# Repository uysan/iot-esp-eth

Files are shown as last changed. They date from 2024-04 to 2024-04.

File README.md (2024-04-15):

# ESP32 Ethernet, Wi-Fi & Serial Gateway

_Open Source Hardware Developed With Open Source Software_ [*](#development-software)

## Overview

<picture>
  <source media="(prefers-color-scheme: dark)" srcset="./pcb/3dviewb.png">
  <source media="(prefers-color-scheme: light)" srcset="./pcb/3dvieww.png">
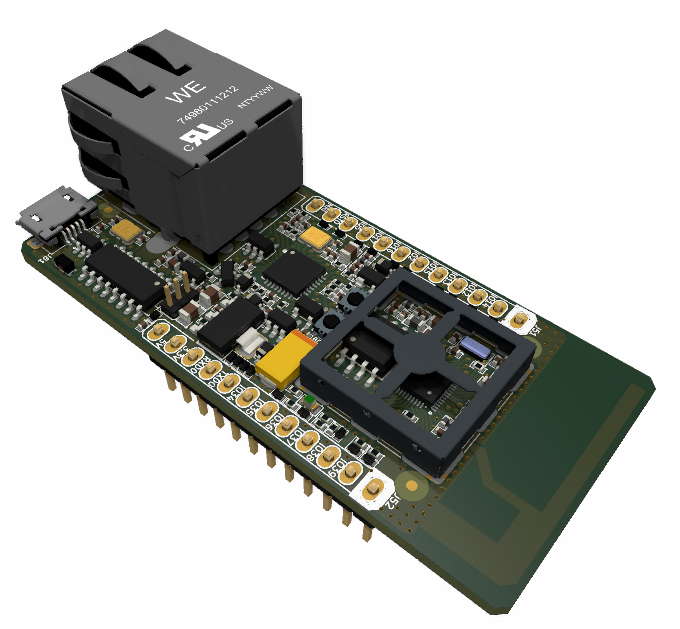
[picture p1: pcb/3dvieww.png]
3D view.
  
</picture>

A hardware design which includes ESP32, Ethernet, Wi-Fi, USB and serial connectivity. **iot-esp-eth** is suitable to use as a gateway between Ethernet, Wi-Fi and serial. When used with [esp-at](https://github.com/espressif/esp-at) project, you can connect wired or wireless networks with AT commands sent to USB or serial ports. You may also operate it with custom firmware, since it is not different from a usual ESP32 development kit.

**iot-esp-eth** may be used as an attachment to a base board. Standalone usage with USB supply is possible as well.

ESP-IDF automatic bootloader activation is supported on USB port. This port is connected to UART0 of ESP32.

Schematic, PCB layout and antenna design are available in this repository. **iot-esp-eth** is compatible with many example projects at [espressif](https://github.com/espressif/) github repository.

## Table of Contents

- [PCB Design](./pcb/) : KiCAD project including schematic, layout, BOM, Gerber files.
- [Antenna Design](./antenna/) : OpenEMS project for PCB antenna design including simulation scripts, figures and prototype measurements.
- [Firmware](./firmware/) : espressif/esp-at project modified to include iot-esp-eth configuration.
- [Documents](./document/) : Project files for diagrams and documents.

## Pinout Diagram

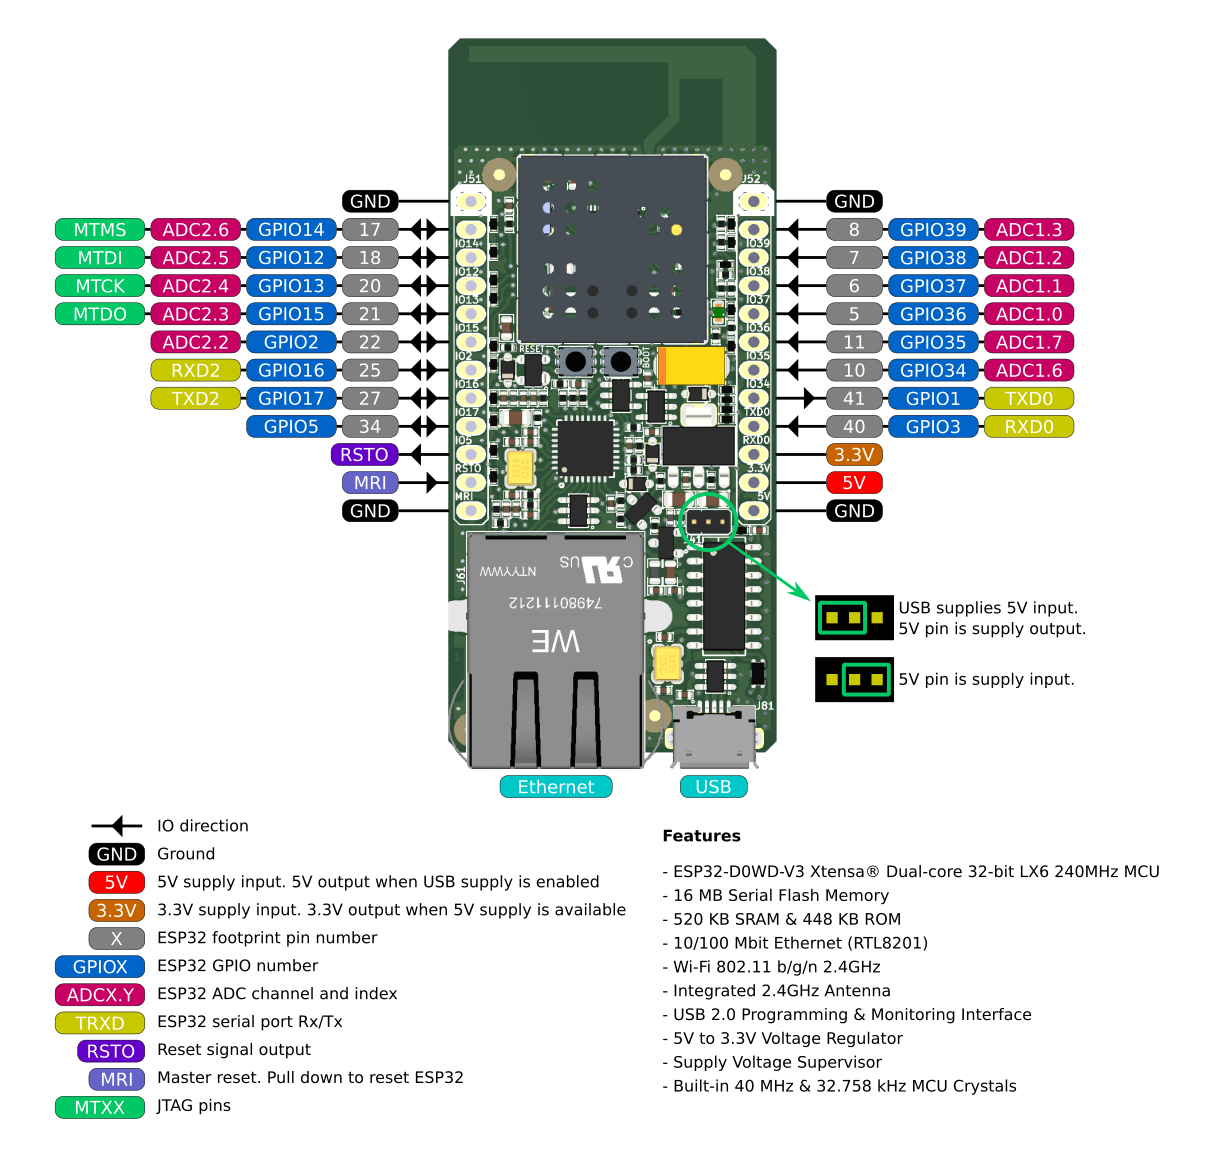
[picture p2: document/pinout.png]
Pinout


## Block Diagram

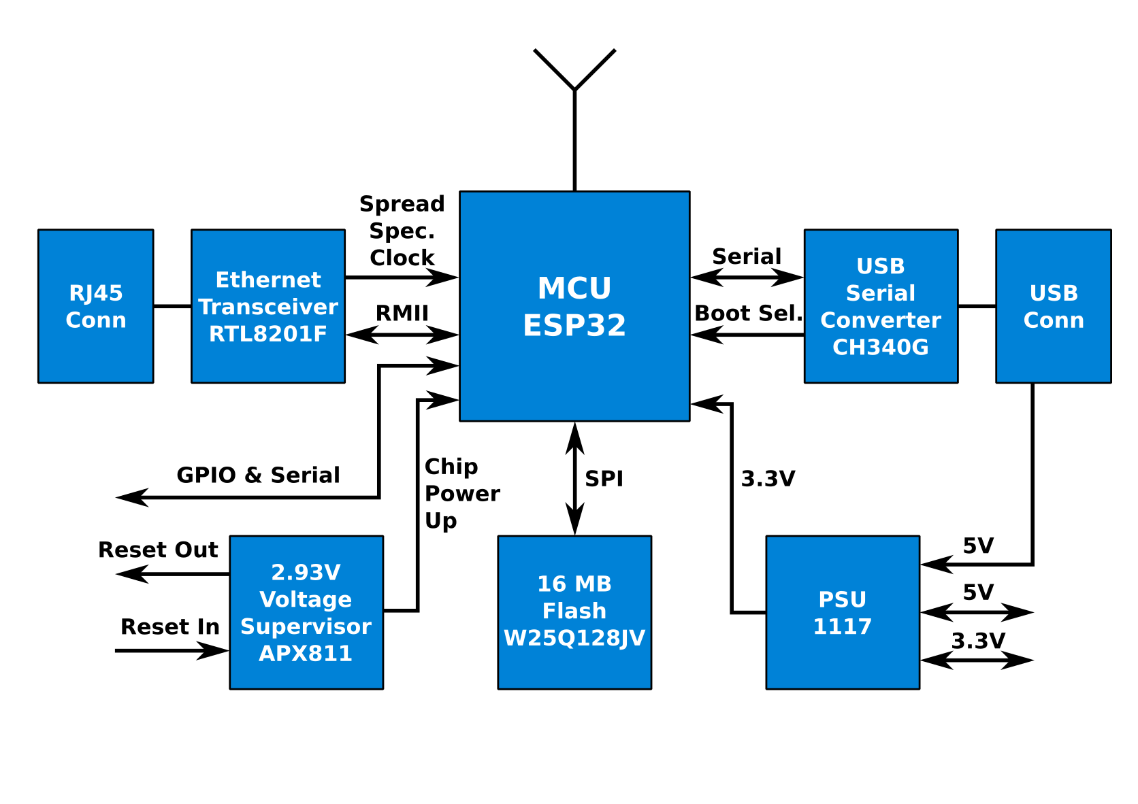
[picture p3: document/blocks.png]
Blocks


## Datasheet

[UYS2101IA, UYS2101CA - ESP32 Ethernet, Wi-Fi & Serial Gateway](./document/uys2101.pdf)

## Features

- ESP32-D0WD-V3 Xtensa® Dual-core 32-bit LX6 240MHz MCU 
- 16 MB Serial Flash Memory
- 520 KB SRAM & 448 KB ROM
- 10/100 Mbit Ethernet (RTL8201F)
- Wi-Fi 802.11 b/g/n 2.4GHz
- Integrated 2.4GHz Antenna
- USB 2.0 Programming & Monitoring Interface
- 5V to 3.3V Voltage Regulator
- Supply Voltage Supervisor
- Built-in 40 MHz & 32.758 kHz MCU Crystals

## Development Software

This project was developed with open source tools including but not limited to KiCAD, OpenEMS, Octave, FreeCAD, Paraview, Inkscape and Scribus on a PC running Ubuntu Desktop edition.

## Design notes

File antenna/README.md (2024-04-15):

# ESP32 Ethernet, Wi-Fi & Serial Gateway

_Open Source Hardware Developed With Open Source Software_ [*](#development-software)

## Antenna Design, Simulation and Measurement

<picture>
  <source media="(prefers-color-scheme: dark)" srcset="../pcb/antviewb.png">
  <source media="(prefers-color-scheme: light)" srcset="../pcb/antvieww.png">
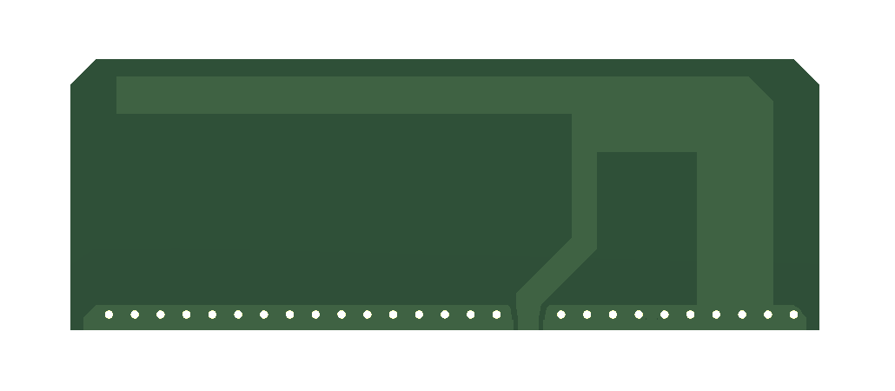
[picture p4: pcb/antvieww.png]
3D view.
  
</picture>

Antenna simulations are made with OpenEMS. The board layout and critical components are defined as geometries in an Octave script.

Initially, coarse dimensions for Inverted-F antenna are obtained from text books and entered to script. Then many iterations are made with OpenEMS to match antenna impedance to 50 ohms at the center frequency (2440MHz). At the same time, VSWR should be acceptable for the operation range from 2400 to 2480 MHz.

The board layout is defined exactly the same as the 4-layer stack up definitions from the manufacturer. If another stack up or material to be used, simulations and prototypes should be updated accordingly.

When the simulation results are satisfactory, geometries are exported from AppCSXCAD and imported to KiCAD to draw the board edges and the antenna as exactly as possible.

Antenna measurements are made with a LiteVNA64. The calibration is done with high-frequency SMD resistors on the matching components' pads since using SMA or similar connectors alters the results drastically.

S1P file exported from VNA is imported to smith chart software (SimNEC) to calculate the matching component values to match ESP32 output impedance to 50 ohms antenna impedance.

It can be seen that the measurement results are consistent with the simulations.

View of geometries before simulation:

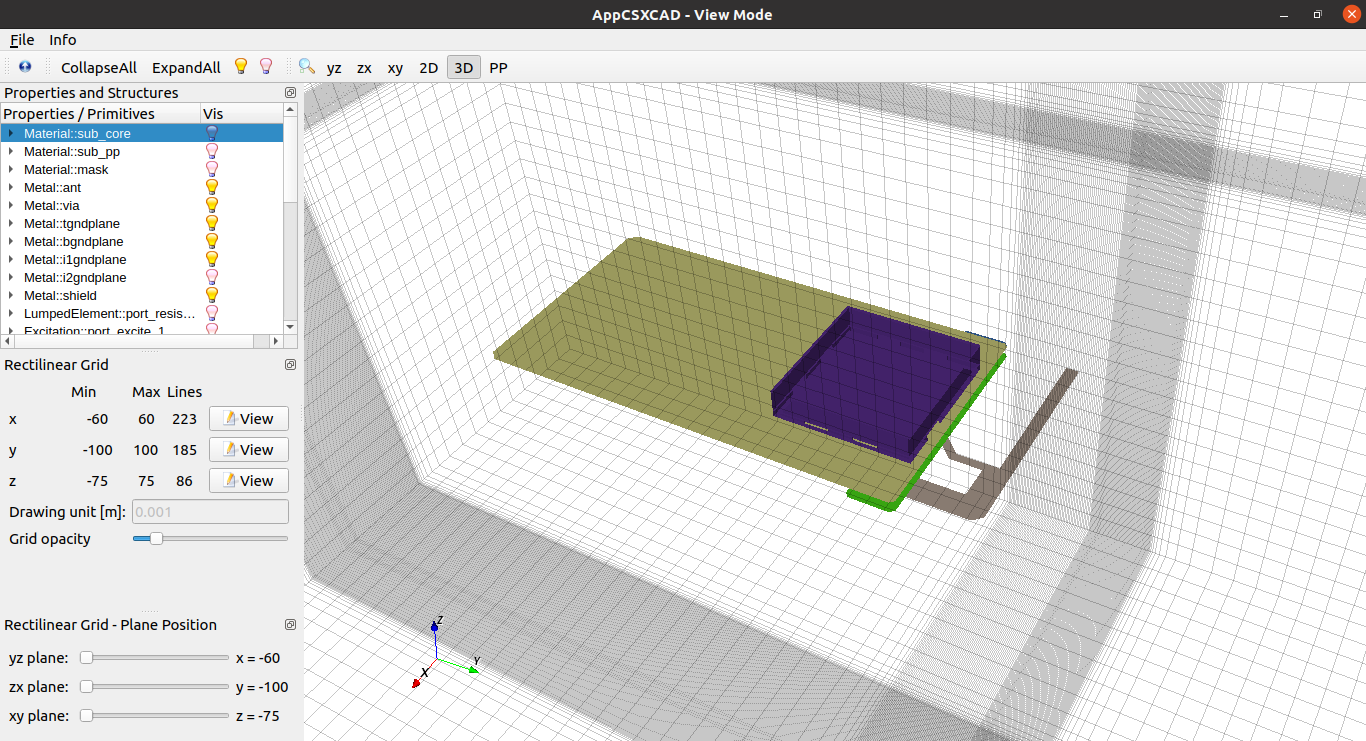
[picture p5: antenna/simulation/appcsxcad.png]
AppCSXCAD


Simulated S11 parameters:

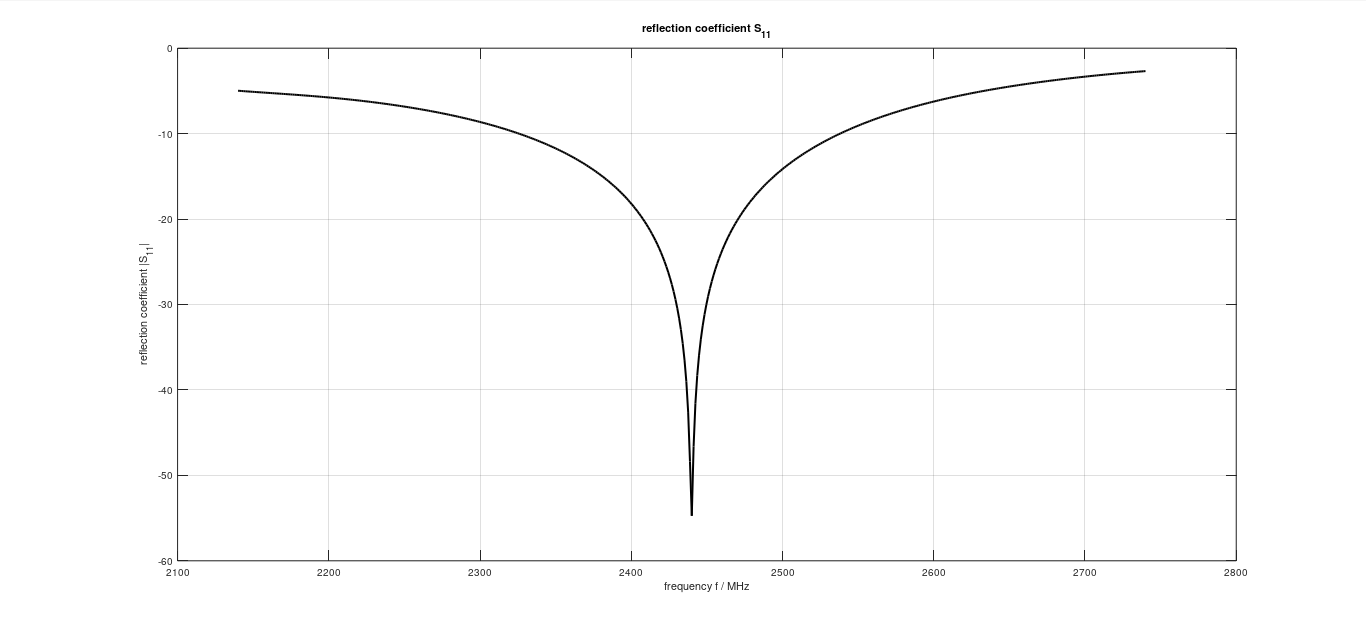
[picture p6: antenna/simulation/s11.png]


Simulated smith chart:

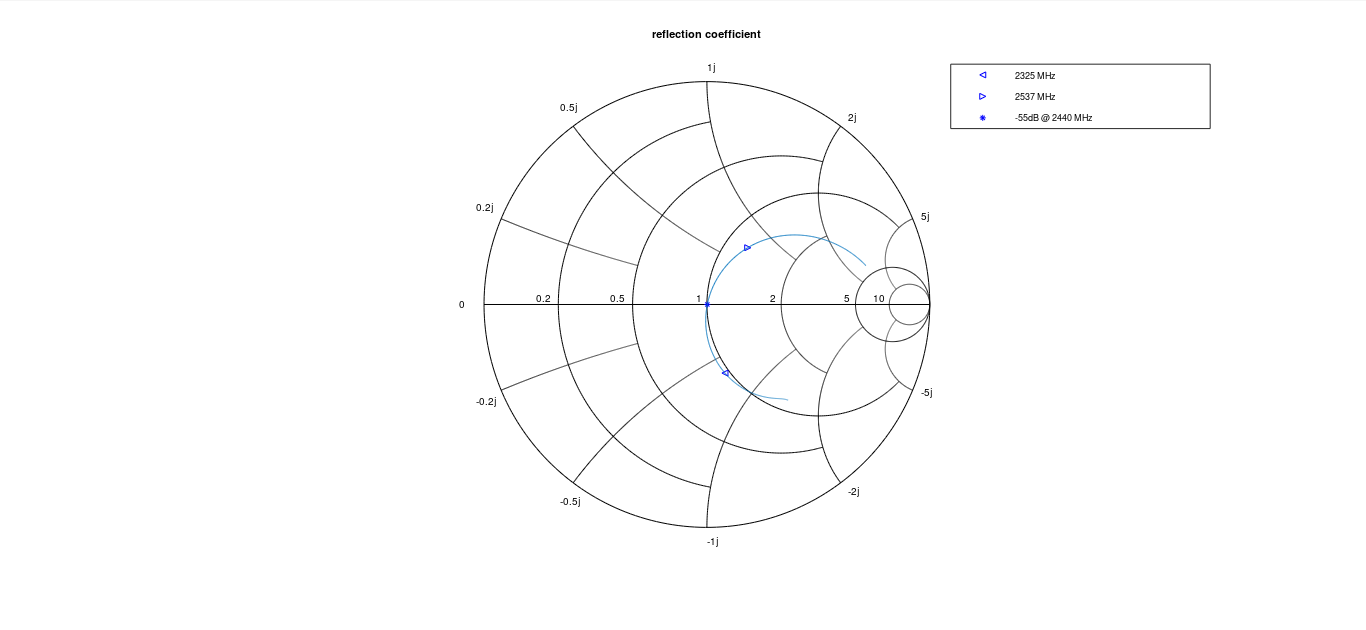
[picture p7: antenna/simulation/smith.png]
smith


Simulated feed point impedance:

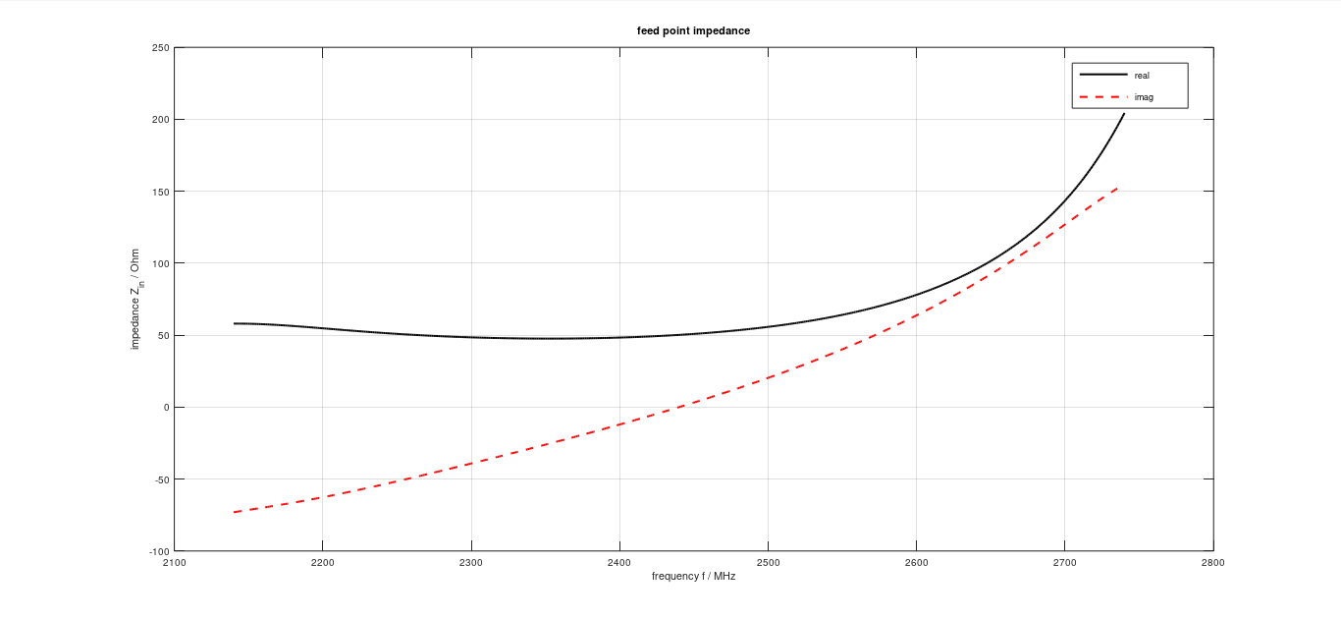
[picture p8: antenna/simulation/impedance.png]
impedance


Simulated 3D radiation:

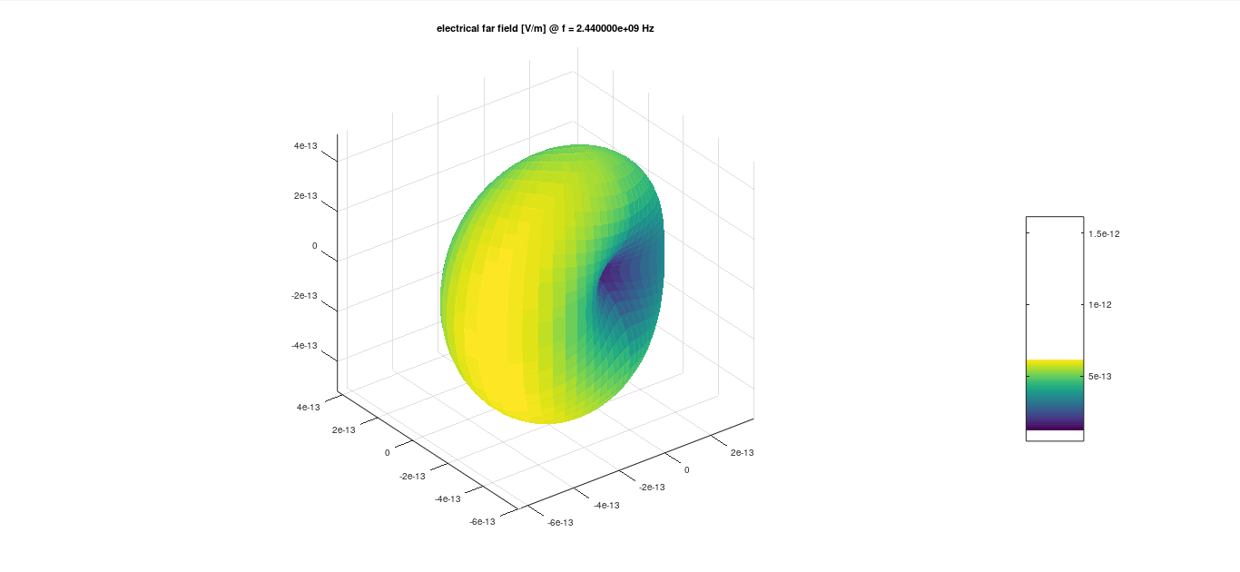
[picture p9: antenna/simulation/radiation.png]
radiation


Measured S11 parameters:

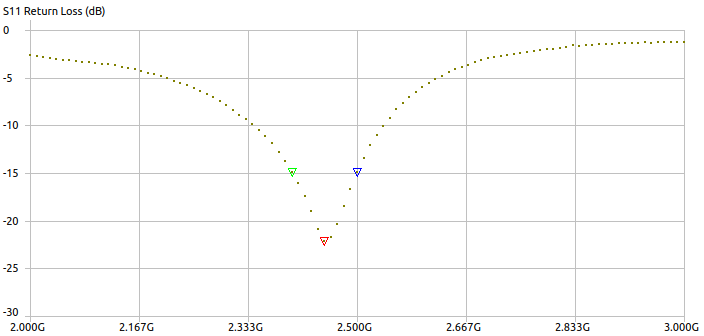
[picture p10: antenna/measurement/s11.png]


Measured smith chart:

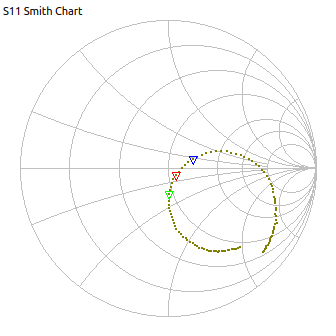
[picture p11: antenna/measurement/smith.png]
smith


Measured phase graph:

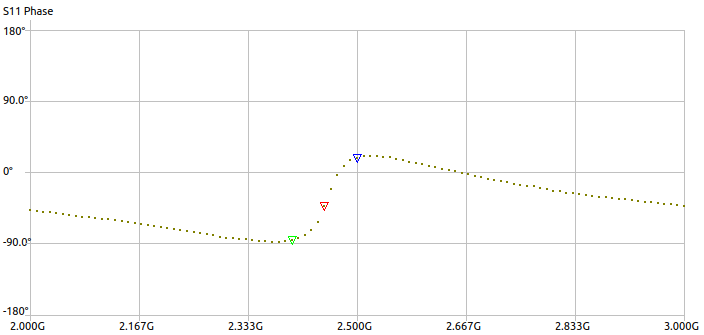
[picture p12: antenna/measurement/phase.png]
phase


## Files

[Octave Simulation Script](./simulation.m)

[Simulation Results And Figures](./simulation/)

[VNA Measurements](./measurement/)

[VNA Measurement Data](./measurement/measurement.s1p)

[Exported Geometries](./stl/)

## Development Software

This project was developed with open source tools including but not limited to KiCAD, OpenEMS, Octave, FreeCAD, Paraview, Inkscape and Scribus on a PC running Ubuntu Desktop edition.

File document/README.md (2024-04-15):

# ESP32 Ethernet, Wi-Fi & Serial Gateway

_Open Source Hardware Developed With Open Source Software_ [*](#development-software)

## Overview

This directory contains Inkscape SVG files, drawings and documents.

## Development Software

This project was developed with open source tools including but not limited to KiCAD, OpenEMS, Octave, FreeCAD, Paraview, Inkscape and Scribus on a PC running Ubuntu Desktop edition.

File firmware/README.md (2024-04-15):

# ESP32 Ethernet, Wi-Fi & Serial Gateway

_Open Source Hardware Developed With Open Source Software_ [*](#development-software)

## Overview

Default firmware on **iot-esp-eth** board is a modified version of [esp-at](https://github.com/espressif/esp-at) project. This project is linked to this repository as a submodule. After initializing the submodule, you can apply the necessary patch and compile the code for **iot-esp-eth**.

Clone the project into your local directory:
```
git clone https://github.com/uysan/iot-esp-eth.git
```

Initialize esp-at submodule and apply the patch:
```
cd iot-esp-eth/
git submodule update --init --depth 1
git apply firmware/esp-at.patch
```

Install esp-idf environment and tools:
```
cd firmware/esp-at/
./build.py install
```

Build script asks for some configuration:
```
Platform name:
1. PLATFORM_ESP32
2. PLATFORM_ESP32C3
3. PLATFORM_ESP32C2
4. PLATFORM_ESP32C6
choose(range[1,4]): 1  <-- Enter 1 here

Module name:
1. WROOM-32
2. WROVER-32
3. PICO-D4
4. SOLO-1
5. MINI-1 (description: ESP32-U4WDH chip inside)
6. ESP32-SDIO
7. ESP32-D2WD (description: 2MB flash, No OTA)
8. IOT-ESP-ETH (description: 16MB flash, Ethernet)
choose(range[1,8]): 8  <-- Enter 8 here

Enable silence mode to remove some logs and reduce the firmware size?
0. No
1. Yes
choose(range[0,1]): 1  <-- Enter 1 here
```

Build the code:
```
./build.py build
```

Then connect iot-esp-eth board to your computer with a USB cable and upload the firmware:
```
./build.py -p /dev/ttyUSB0 flash
```

You may use your preferred serial terminal software to enter AT commands. For picocom:
```
picocom /dev/ttyUSB0 -b 115200 --omap crcrlf
```

## Development Software

This project was developed with open source tools including but not limited to KiCAD, OpenEMS, Octave, FreeCAD, Paraview, Inkscape and Scribus on a PC running Ubuntu Desktop edition.

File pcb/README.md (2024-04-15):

# ESP32 Ethernet, Wi-Fi & Serial Gateway

_Open Source Hardware Developed With Open Source Software_ [*](#development-software)

## Overview

> [!NOTE]
> This directory contains two versions of **iot-esp-eth** hardware design. There are small differences between board layouts, but bill of materials differ a lot. Components of the **iot-esp-eth-ind** board has an operating range of -40॰C to +85॰C, whereas the **iot-esp-eth-com** board is for 0॰C to 70॰C.
> Both have 4-layers and are designed according to the JLCPCB impedance controlled stack up of [JLC04161H-7628](https://jlcpcb.com/impedance).

**iot-esp-eth** design is based on Espressif ESP32-D0WD-V3 Xtensa® Dual-core 32-bit LX6 240MHz MCU. It has 520 kB SRAM and 448 kB ROM but no flash memory. Winbond W25Q128JVSIQ SPI flash chip is used as an application and data storage with a 16MB capacity. One 40MHz and one 32.768kHz crystal are used as clock sources of the MCU. These components are enclosed with an RF shield to decrease EMC interference.

Wi-Fi and 2.4GHz wireless are built in ESP32. The only required external component is an antenna. An Inverted-F type PCB antenna is designed for **iot-esp-eth** by using EM simulation tools. Since the output impedance of ESP32's RF amplifier is different from 50 ohms, an L-type matching circuit is populated.

ESP32 has an RMII interface. Realtek RTL8201F transceiver is connected through this interface for Ethernet connectivity. Ethernet transformers are included in the RJ45 connector and this leads to a compact design. Ethernet clock is generated by RTL8201F and supplied to the ESP32. This chip has spread spectrum ability to lower radiated emissions. There is a 3-state buffer (74AUP1G126) on the clock signal to disable the clock while ESP32 is initializing. The clock input of ESP32 (GPIO0) is a bootstrapped input.

**iot-esp-eth** has two extension pin headers in order to connect it to another custom design base boards.

ESP32's UART0 is used for flash programming and general purpose cases. This port is connected to both extension pin header and the Serial-USB converter chip (CH340G). There is an AND gate (74AHC1G08) between RXD pins to prevent shorts when USB and serial port pins are used at the same time. ESP-IDF's automatic bootloader activation is supported on USB port.

**iot-esp-eth** has an onboard 5 to 3.3V linear regulator. It is possible to supply the board with 5V or 3.3V via the extension headers. If USB power is available, 5V and 3.3V pins on the headers can supply exernal circuits.

There is a voltage supervisory chip to generate reset pulses 200ms wide when necessary or when the voltage drops below minimum required. Two buttons can be used to reset the circuit or enter serial bootloader after reset.

**iot-esp-eth** has ESD protection on extension headers, antenna, Ethernet and USB ports, and has common mode chokes on Ethernet and USB ports.

## Images

Copper layers:

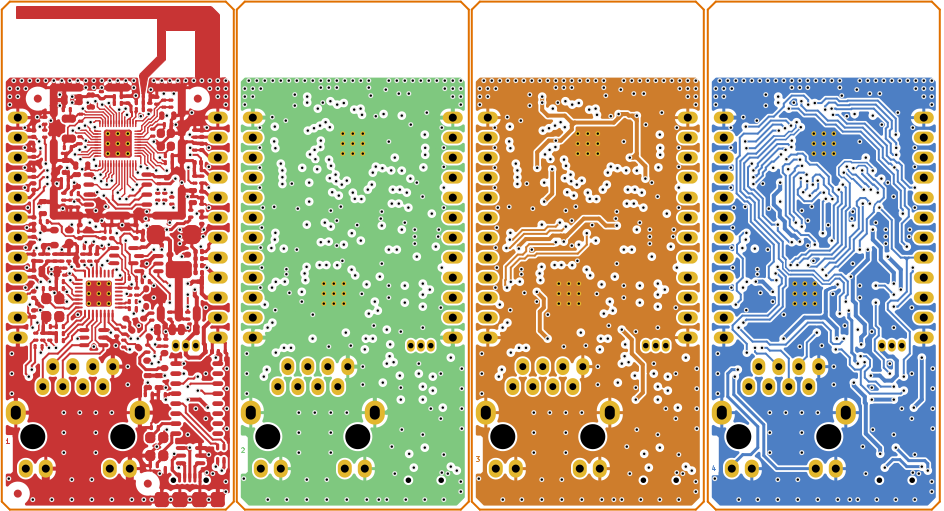
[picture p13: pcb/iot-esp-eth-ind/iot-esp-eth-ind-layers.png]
Copper layers.


Top view:

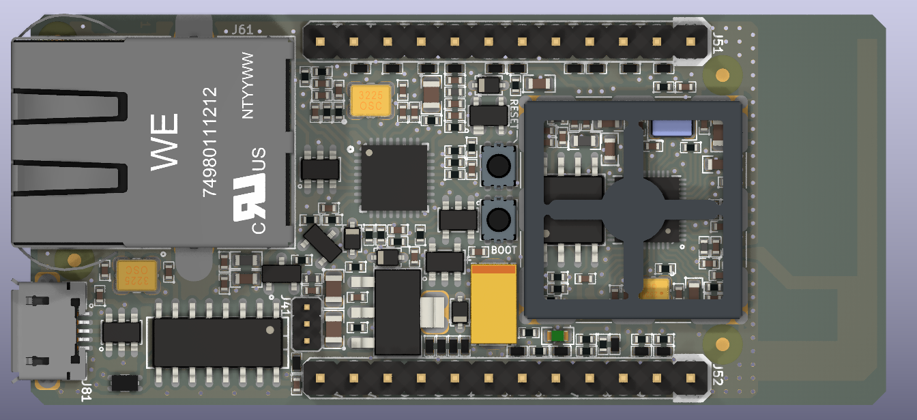
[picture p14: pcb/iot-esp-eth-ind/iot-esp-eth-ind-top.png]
Top view.


Bottom view:

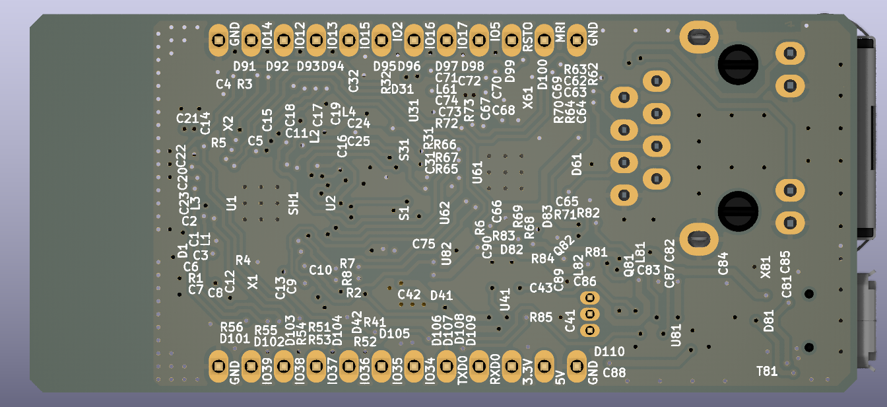
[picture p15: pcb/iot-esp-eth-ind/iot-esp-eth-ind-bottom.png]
Bottom view.


## Development Software

This project was developed with open source tools including but not limited to KiCAD, OpenEMS, Octave, FreeCAD, Paraview, Inkscape and Scribus on a PC running Ubuntu Desktop edition.

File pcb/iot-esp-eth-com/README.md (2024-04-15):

# ESP32 Ethernet, Wi-Fi & Serial Gateway

_Open Source Hardware Developed With Open Source Software_ [*](#development-software)

## Overview

This directory contains KiCAD project files, generated PCB images, Gerber, panel configuration files, interactive HTML based assembly list, bill of materials and position (pick & place) data.

Components of the **iot-esp-eth-com** board has an operating range of 0॰C to 70॰C. Board layout has 4-layers and is designed according to the JLCPCB impedance controlled stack up of [JLC04161H-7628](https://jlcpcb.com/impedance).

PCB panels can be automatically generated with KiKit (KiCAD plugin). Configuration files are in the related directory.

## Files

[Schematics](./iot-esp-eth-com.pdf)

[PCB Layers](./iot-esp-eth-com-layers.pdf)

[Bill of Materials](./iot-esp-eth-com-bom.csv)

[Position Data](./iot-esp-eth-com-all-pos.csv)

[Interactive assembly part list](./bom/ibom.html)

[Panel Configuration](./panel/config.json)

[Dimensions](./iot-esp-eth-com-dimensions.pdf)

## Images

Copper layers:

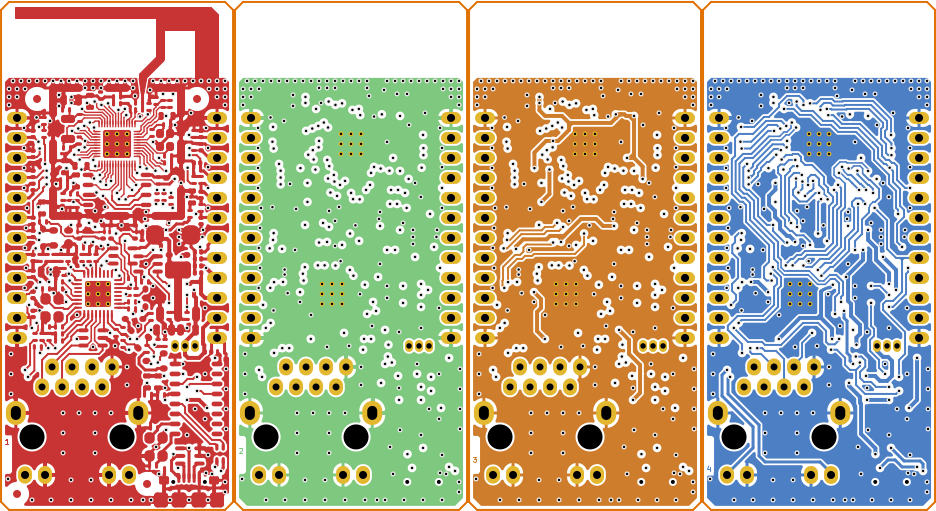
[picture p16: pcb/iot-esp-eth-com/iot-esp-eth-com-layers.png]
Copper layers.


Top view:

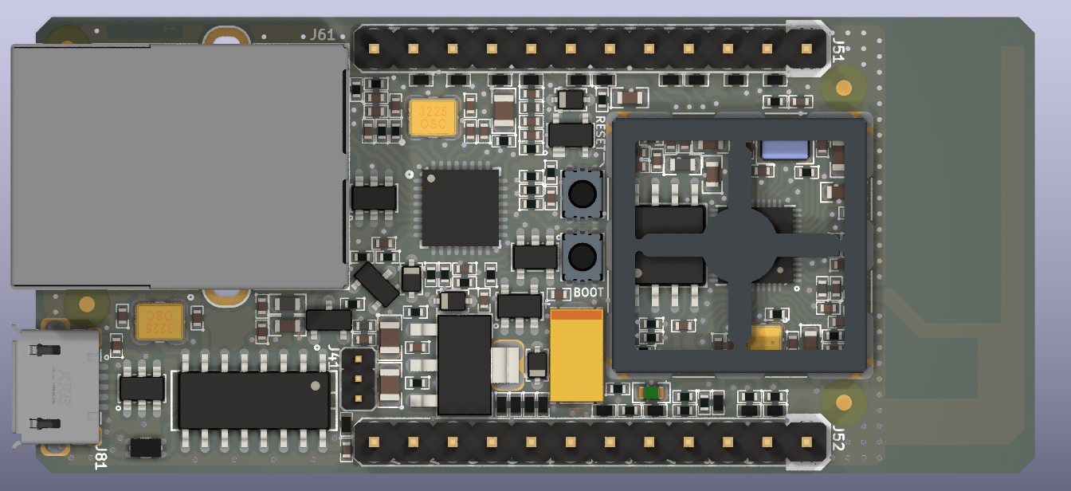
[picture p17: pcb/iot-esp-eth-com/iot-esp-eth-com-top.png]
Top view.


Bottom view:

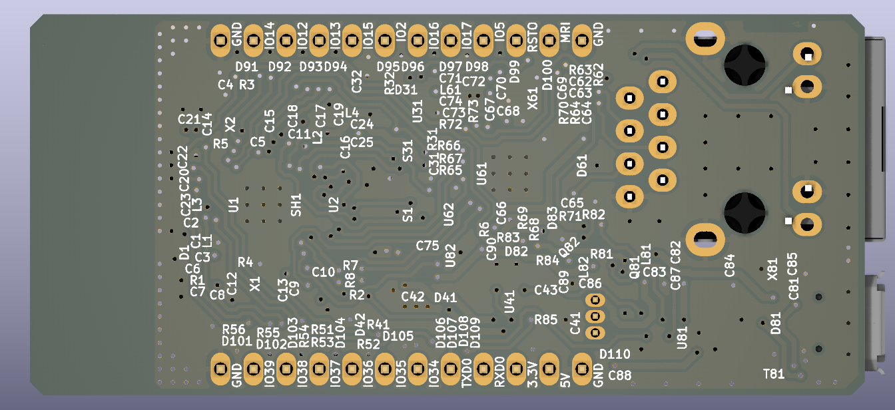
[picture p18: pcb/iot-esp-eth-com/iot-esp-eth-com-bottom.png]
Bottom view.


## Development Software

This project was developed with open source tools including but not limited to KiCAD, OpenEMS, Octave, FreeCAD, Paraview, Inkscape and Scribus on a PC running Ubuntu Desktop edition.

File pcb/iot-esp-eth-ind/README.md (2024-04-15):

# ESP32 Ethernet, Wi-Fi & Serial Gateway

_Open Source Hardware Developed With Open Source Software_ [*](#development-software)

## Overview

This directory contains KiCAD project files, generated PCB images, Gerber, panel configuration files, interactive HTML based assembly list, bill of materials and position (pick & place) data.

Components of the **iot-esp-eth-ind** board has an operating range of -40॰C to +85॰C. Board layout has 4-layers and is designed according to the JLCPCB impedance controlled stack up of [JLC04161H-7628](https://jlcpcb.com/impedance).

PCB panels can be automatically generated with KiKit (KiCAD plugin). Configuration files are in the related directory.

## Files

[Schematics](./iot-esp-eth-ind.pdf)

[PCB Layers](./iot-esp-eth-ind-layers.pdf)

[Bill of Materials](./iot-esp-eth-ind-bom.csv)

[Position Data](./iot-esp-eth-ind-all-pos.csv)

[Interactive assembly part list](./bom/ibom.html)

[Panel Configuration](./panel/config.json)

[Dimensions](./iot-esp-eth-ind-dimensions.pdf)

## Images

Copper layers:

Copper layers.

Top view:

Top view.

Bottom view:

Bottom view.

## Development Software

This project was developed with open source tools including but not limited to KiCAD, OpenEMS, Octave, FreeCAD, Paraview, Inkscape and Scribus on a PC running Ubuntu Desktop edition.

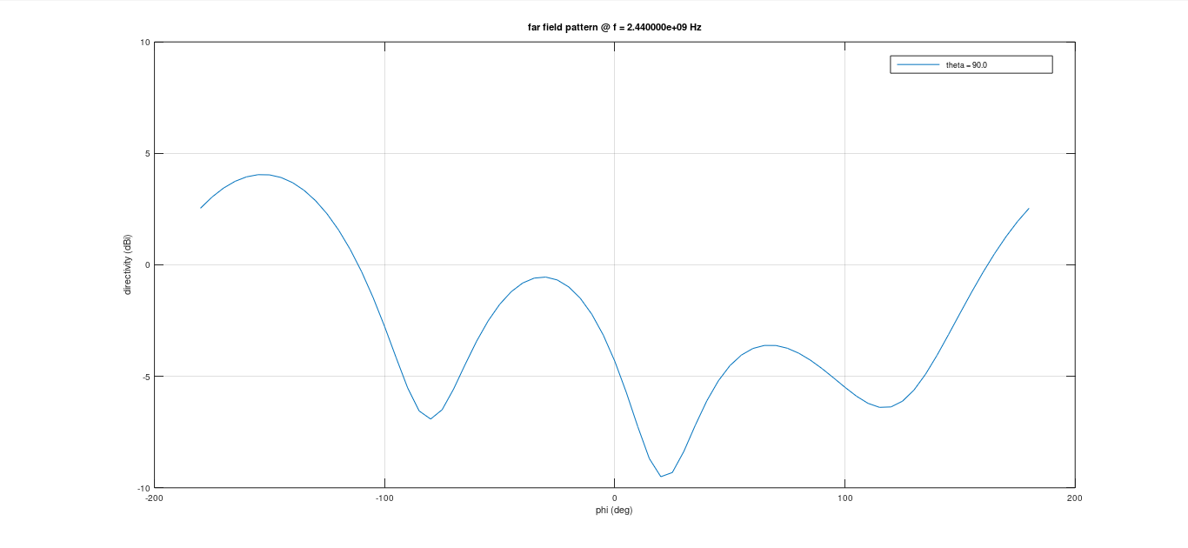
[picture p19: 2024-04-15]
antenna/simulation/ff2.png

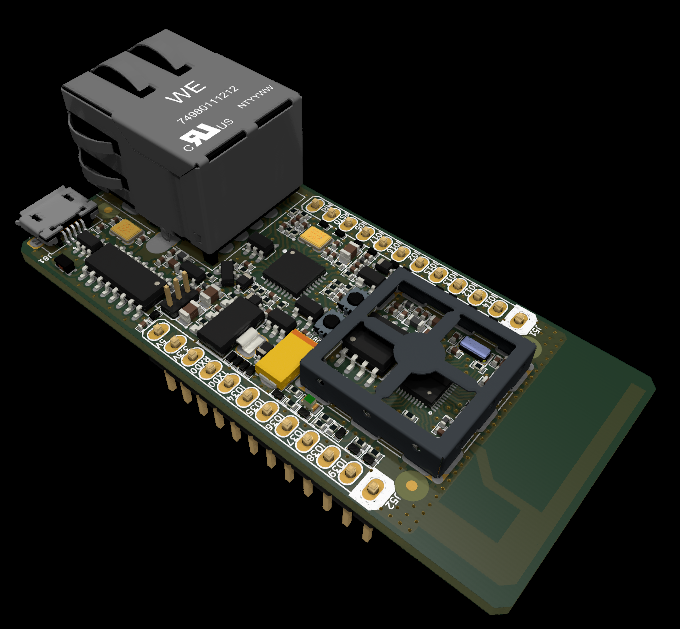
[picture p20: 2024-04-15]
pcb/3dviewb.png

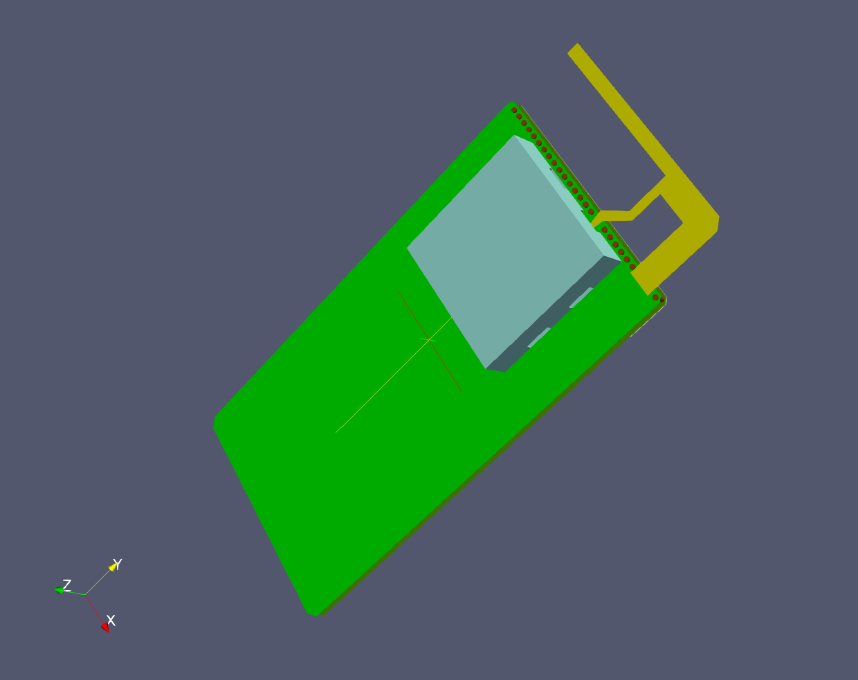
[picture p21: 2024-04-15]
antenna/simulation/paraview.png

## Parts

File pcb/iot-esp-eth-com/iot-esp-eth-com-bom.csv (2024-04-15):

Reference | Quantity | Value | Footprint | Datasheet | Digikey | Manufacturer | PartNumber | Power | Temperature | Tolerance
C1 | 1 | 0.9pF/50V | Celebi:SM0402C | https://www.we-online.com/catalog/datasheet/885392005022.pdf | !13-CC0402BRNPO9BNR90CT-ND | Wurth | 885392005022 | _ | -55+125°C | 0.1pF
C12,C13 | 2 | 12pF/50V | Celebi:SM0402C | https://www.yageo.com/en/Chart/Download/pdf/CC0402JRNPO9BN120 | 311-1016-1-ND | Yageo | CC0402JRNPO9BN120 | _ | -55+125°C | 5%
C14,C15,C69,C70 | 4 | 18pF/50V | Celebi:SM0402C | https://www.yageo.com/en/Chart/Download/pdf/CC0402JRNPO9BN180 | 311-1415-1-ND | Yageo | CC0402JRNPO9BN180 | _ | -55+125°C | 5%
C10,C16,C17,C2,C20,C25,C3,C31,C43,C5,C62,C63,C64,C65,C66,C67,C68,C71,C74,C75,C86,C87,C88,C90 | 24 | 100nF/16V | Celebi:SM0402C | http://weblib.samsungsem.com/mlcc/mlcc-ec-data-sheet.do?partNumber=CL05B104KO5NNN | 1276-1001-1-ND | Samsung | CL05B104KO5NNNC | _ | -55+125°C | 10%
C21,C41,C72,C89 | 4 | 10uF/16V | Celebi:SM0805C | http://weblib.samsungsem.com/mlcc/mlcc-ec-data-sheet.do?partNumber=CL21B106KOQNNN | 1276-2872-1-ND | Samsung | CL21B106KOQNNNE | _ | -55+125°C | 10%
C32 | 1 | 100nF/50V | Celebi:SM0603C | http://weblib.samsungsem.com/mlcc/mlcc-ec-data-sheet.do?partNumber=CL10B104KB8NNN | 1276-1000-1-ND | Samsung | CL10B104KB8NNNC | _ | -55+125°C | 10%
C4,C7 | 2 | 3.3nF/50V | Celebi:SM0402C | http://weblib.samsungsem.com/mlcc/mlcc-ec-data-sheet.do?partNumber=CL05B332KB5NNN | 1276-1552-1-ND | Samsung | CL05B332KB5NNNC | _ | -55+125°C | 10%
C42 | 1 | 47uF/16V | Celebi:SMD-C-6032 | https://spicat.kyocera-avx.com/product/tan/chartview/TAJC476K016RNJ/DataSheet/gen_taj/TAJC476_016_NJ | 478-1718-1-ND | Kyocera_AVX | TAJC476K016RNJ | _ | -55+125°C | 10%
C6 | 1 | 10nF/50V | Celebi:SM0402C | https://www.yageo.com/en/Chart/Download/pdf/CC0402KRX7R9BB103 | 311-1349-1-ND | Yageo | CC0402KRX7R9BB103 | _ | -55+125°C | 10%
C11,C18,C22,C8,C83 | 5 | 1uF/16V | Celebi:SM0603C | https://www.yageo.com/en/Chart/Download/pdf/CC0603KRX7R7BB105 | 311-1446-1-ND | Yageo | CC0603KRX7R7BB105 | _ | -55+125°C | 10%
C81 | 1 | 100nF/50V | Celebi:SM0402C | https://www.yageo.com/en/Chart/Download/pdf/CC0402KRX7R9BB104 | 311-3566-1-ND | Yageo | CC0402KRX7R9BB104 | _ | -55+125°C | 10%
C84,C85 | 2 | 27pF/50V | Celebi:SM0402C | https://www.yageo.com/en/Chart/Download/pdf/CC0402JRNPO9BN270 | 311-1019-1-ND | Yageo | CC0402JRNPO9BN270 | _ | -55+125°C | 5%
C19,C23,C24,C73,C82,C9 | 6 | 15pF/50V | Celebi:SM0402C | https://www.yageo.com/en/Chart/Download/pdf/CC0402JRNPO9BN150 | 311-1017-1-ND | Yageo | CC0402JRNPO9BN150 | _ | -55+125°C | 5%
D1 | 1 | TVS_4V | Celebi:SM0402V | https://www.murata.com/products/productdata/8796832759838/CRESD-E.pdf | 490-13210-2-ND | Murata | LXES15AAA1-153 | 15kV | -40+85°C | _
D31,D41,D82,D83 | 4 | BAT54WS | Celebi:SOD323 | https://www.panjit.com.tw/upload/datasheet/BAT54WS.pdf | 3757-BAT54WS_R1_00001CT-ND | Panjit | BAT54WS_R1_00001 | 0.2A | -55+125°C | _
D42 | 1 | Diode-LED_Green | Celebi:led-SM0603_Green | https://optoelectronics.liteon.com/upload/download/DS22-2000-228/LTST-C191KGKT.PDF | 160-1446-1-ND | Liteon | LTST-C191KGKT | 0.075W | -55+85°C | _
D61,D81 | 2 | TVS_5V | Celebi:SOT23-6L | https://en.leiditech.com/u_file/file/products/2212/13/392447b971.pdf | !497-4492-1-ND | Leiditech | USRV05-4 | 350W | -55+125°C | _
D100,D101,D102,D103,D104,D105,D106,D107,D108,D109,D110,D91,D92,D93,D94,D95,D96,D97,D98,D99 | 20 | TVS_5V | Celebi:DFN1006-2 | https://en.leiditech.com/u_file/file/products/2212/16/1ac2f97961.pdf | !490-12804-1-ND | Leiditech | ULC0511CDN | 110W | -55+150°C | _
E41 | 1 | Jumper | Celebi:N.A. | https://datasheet.lcsc.com/lcsc/2201121830_XKB-Connectivity-X1301-B1NIB_C2938575.pdf | !S9345-ND | XKB | X1301-B1NIB | 1A | -40+105°C | _
J41 | 1 | Conn_01x03 | Celebi:sil-1.27mm-3P | https://www.helloxkb.com/public/images/pdf/X1311WV-XXJ-C18D27.pdf | !SAM10238-ND | XKB | X1311WV-03J-C18D27 | 1A | -40+105°C | _
J51,J52 | 2 | Conn_01x12/DNP | Celebi:sil-12P | https://www.helloxkb.com/public/images/pdf/X6511WV-XXH-C60D30.pdf | !S1012EC-12-ND | XKB | X6511WV-12H-C60D30 | 3A | -40+105°C | _
J61 | 1 | HR913550A | Celebi:eth-HR911105A | https://datasheet.lcsc.com/lcsc/1811141123_HANRUN-Zhongshan-HanRun-Elec-HR913550A_C163507.pdf | _ | Hanrun | HR913550A | _ | 0+85°C | _
J81 | 1 | USB-Micro | Celebi:usb-U253-05XX-4BH89-XXS | http://www.helloxkb.com/public/images/pdf/U253-05XX-4BH89-XXS.pdf | !732-3155-1-ND | XKB | U253-051N-4BH89-S1S | 1A | -40+85°C | _
L1 | 1 | 2.2nH | Celebi:SM0402L | https://www.we-online.com/catalog/datasheet/7447840022G.pdf | 732-7447840022GCT-ND | Wurth | 7447840022G | 0.3A | -55+125°C | 0.1nH
L2,L81 | 2 | Bead_300R | Celebi:SM0603L | https://www.we-online.com/catalog/datasheet/742792641.pdf | 732-1592-1-ND | Wurth | 742792641 | 2A | -55+125°C | 25%
L3 | 1 | 2nH | Celebi:SM0402L | https://www.we-online.com/catalog/datasheet/744765020A.pdf | 732-1705-1-ND | Wurth | 744765020A | 1.04A | -40+125°C | 0.2nH
L4 | 1 | Bead_220R/DNP | Celebi:SM0402L | https://www.we-online.com/catalog/datasheet/742792780.pdf | 732-1569-1-ND | Wurth | 742792780 | 0.3A | -55+125°C | 25%
L61,L82 | 2 | Bead_220R | Celebi:SM0402L | https://www.we-online.com/catalog/datasheet/742792780.pdf | 732-1569-1-ND | Wurth | 742792780 | 0.3A | -55+125°C | 25%
M1 | 1 | Shield_Cover | Celebi:N.A. | https://www.we-online.com/catalog/datasheet/36003160s.pdf | 732-11644-1-ND | Wurth | 36003160S | _ | -40+125°C | _
Q81,Q82 | 2 | BC817 | Celebi:SOT23-3 | https://assets.nexperia.com/documents/data-sheet/BC817_SER.pdf | 1727-2919-1-ND | Nexperia | BC817-40-215 | 0.5A | -65+150°C | _
R1 | 1 | 20k | Celebi:SM0402 | https://www.yageo.com/upload/media/product/productsearch/datasheet/rchip/PYu-RC_Group_51_RoHS_L_12.pdf | 311-20.0KLRCT-ND | Yageo | RC0402FR-0720KL | 1/16W | -55+155°C | 1%
R2 | 1 | 499R | Celebi:SM0402 | https://www.yageo.com/upload/media/product/productsearch/datasheet/rchip/PYu-RC_Group_51_RoHS_L_12.pdf | 311-499LRCT-ND | Yageo | RC0402FR-07499RL | 1/16W | -55+155°C | 1%
R3,R32 | 2 | 100R | Celebi:SM0402 | https://www.yageo.com/upload/media/product/productsearch/datasheet/rchip/PYu-RC_Group_51_RoHS_L_12.pdf | 311-100LRCT-ND | Yageo | RC0402FR-07100RL | 1/16W | -55+155°C | 1%
R31 | 1 | 100k | Celebi:SM0402 | https://www.yageo.com/upload/media/product/productsearch/datasheet/rchip/PYu-RC_Group_51_RoHS_L_12.pdf | 311-100KLRCT-ND | Yageo | RC0402FR-07100KL | 1/16W | -55+155°C | 1%
R4 | 1 | 0R | Celebi:SM0402 | https://www.yageo.com/upload/media/product/productsearch/datasheet/rchip/PYu-RC_Group_51_RoHS_L_12.pdf | 311-0.0JRCT-ND | Yageo | RC0402JR-070RL | 1/16W | -55+155°C | Jumper
R41 | 1 | 2k7 | Celebi:SM0402 | https://www.yageo.com/upload/media/product/productsearch/datasheet/rchip/PYu-RC_Group_51_RoHS_L_12.pdf | 311-2.70KLRCT-ND | Yageo | RC0402FR-072K7L | 1/16W | -55+155°C | 1%
R5 | 1 | 10Meg | Celebi:SM0402 | https://www.yageo.com/upload/media/product/productsearch/datasheet/rchip/PYu-RC_Group_51_RoHS_L_12.pdf | 311-10.0MLRCT-ND | Yageo | RC0402FR-0710ML | 1/16W | -55+155°C | 1%
R51,R52,R53,R54,R55,R56 | 6 | 470k | Celebi:SM0402 | https://www.yageo.com/upload/media/product/productsearch/datasheet/rchip/Pyu-RC_Group_51_RoHS_L_12.pdf | 311-470KLRCT-ND | Yageo | RC0402FR-07470KL | 1/16W | -55+155°C | 1%
R6,R62,R63,R83,R84 | 5 | 1k | Celebi:SM0402 | https://www.yageo.com/upload/media/product/productsearch/datasheet/rchip/PYu-RC_Group_51_RoHS_L_12.pdf | 311-1.00KLRCT-ND | Yageo | RC0402FR-071KL | 1/16W | -55+155°C | 1%
R64 | 1 | 2k49 | Celebi:SM0402 | https://www.yageo.com/upload/media/product/productsearch/datasheet/rchip/PYu-RC_Group_51_RoHS_L_12.pdf | 311-2.49KLRCT-ND | Yageo | RC0402FR-072K49L | 1/16W | -55+155°C | 1%
R65,R85 | 2 | 47k | Celebi:SM0402 | https://www.yageo.com/upload/media/product/productsearch/datasheet/rchip/PYu-RC_Group_51_RoHS_L_12.pdf | 311-47.0KLRCT-ND | Yageo | RC0402FR-0747KL | 1/16W | -55+155°C | 1%
R66,R67,R81,R82 | 4 | 10k | Celebi:SM0402 | https://www.yageo.com/upload/media/product/productsearch/datasheet/rchip/PYu-RC_Group_51_RoHS_L_12.pdf | 311-10.0KLRCT-ND | Yageo | RC0402FR-0710KL | 1/16W | -55+155°C | 1%
R68,R69,R7,R70,R8 | 5 | 22R | Celebi:SM0402 | https://www.yageo.com/upload/media/product/productsearch/datasheet/rchip/PYu-RC_Group_51_RoHS_L_12.pdf | 311-22.0LRCT-ND | Yageo | RC0402FR-0722RL | 1/16W | -55+155°C | 1%
R71,R72,R73 | 3 | 4k7 | Celebi:SM0402 | https://www.yageo.com/upload/media/product/productsearch/datasheet/rchip/PYu-RC_Group_51_RoHS_L_12.pdf | 311-4.7KLRCT-ND | Yageo | RC0402FR-074K7L | 1/16W | -55+155°C | 1%
S1,S31 | 2 | Tact_Switch | Celebi:switch-WE-WS-TASV-3x2.6_H1.4mm | https://www.dg-switch.com/uploads/soft/190720/GT-TX171X-H014-LX.pdf | !732-435171014816CT-ND | G-Switch | GT-TC171A-H014-L1 | 0.05A | -30+85°C | _
SH1 | 1 | Shield | Celebi:shield-36103166S | https://www.we-online.com/catalog/datasheet/36103166s.pdf | 732-11652-1-ND | Wurth | 36103166S | _ | -40+125°C | _
T81 | 1 | CM_Choke_90R | Celebi:tr-smd-WE-CNSW_0805 | https://www.sunlordinc.com/uploads/files/20230829/SDCW%20series%20of%20Wire%20Wound%20Chip%20Common%20Mode%20Choke%20Coil.pdf | !732-3198-1-ND | Sunlord | SDCW2012-2-900TF | 0.33A | -40+85°C | _
U1 | 1 | ESP32-D0WD | Celebi:QFN48_5x5_P0.35_E3.5mm | https://www.espressif.com/sites/default/files/documentation/esp32_datasheet_en.pdf | 1904-ESP32-D0WD-V3CT-ND | Espressif | ESP32-D0WD-V3 | _ | -40+125°C | _
U2 | 1 | W25Q128JV | Celebi:SO8_5.2x5.2_P1.27mm | https://www.winbond.com/resource-files/W25Q128JV%20RevI%2008232021%20Plus.pdf | W25Q128JVSIQ-ND | Winbond | W25Q128JVSIQ | _ | -40+85°C | _
U31 | 1 | APX811_2.93V | Celebi:SOT143-4 | https://www.diodes.com/assets/Datasheets/APX811_812.pdf | APX811-29UG-7DICT-ND | Diodes | APX811-29UG-7 | _ | -40+85°C | 2%
U41 | 1 | AMS1117-3.3 | Celebi:SOT223 | https://mm.digikey.com/Volume0/opasdata/d220001/medias/docus/5011/AMS1117.pdf | 4518-AMS1117-3.3CT-ND | UMW | AMS1117-3.3 | 1A | -40+125°C | 1.5%
U61 | 1 | RTL8201F | Celebi:QFN32_5x5_P0.5_E3.35mm | https://www.semiee.com/file/Source10/REALTEK-RTL8201F-VB-CG.pdf | _ | Realtek | RTL8201F-VB-CG | _ | 0+70°C | _
U62 | 1 | 74AUP1G126 | Celebi:SOT23-5L | https://www.ti.com/lit/ds/symlink/sn74aup1g126.pdf | 296-18005-1-ND | Texas_Instruments | SN74AUP1G126DBVR | 0.05A | -40+125°C | _
U81 | 1 | CH340G | Celebi:SO16_4x10.5_P1.27mm | http://www.wch-ic.com/downloads/file/79.html | _ | WCH | CH340G | _ | -40+85°C | _
U82 | 1 | 74AHC1G08 | Celebi:SOT23-5L | https://www.ti.com/lit/ds/symlink/sn74ahc1g08.pdf | 296-1091-1-ND | Texas_Instruments | SN74AHC1G08DBVR | 0.05A | -55+125°C | _
X1 | 1 | 40MHz_10pF | Celebi:xtal-2.5x2.0mm_4pin | https://datasheet.lcsc.com/lcsc/2306211601_huaxindianzi-CM4040M00010001_C7294659.pdf | !2151-R2520-40.000-10-F-1010-EXT-TRCT-ND | Huaxin | CM4040M00010001 | _ | -30+85°C | 10ppm
X2 | 1 | 32.768kHz_12.5pF | Celebi:xtal-3.2x1.5mm | https://datasheet.lcsc.com/lcsc/2306211602_huaxindianzi-DF2032K76812001_C7294751.pdf | !2151-RT3215-32.768-12.5-TR-10PPMCT-ND | Huaxin | DF2032K76812001 | _ | -40+85°C | 20ppm
X61 | 1 | 25MHz_12pF | Celebi:xtal-3.2x2.5mm_4pin | https://datasheet.lcsc.com/lcsc/2306211559_huaxindianzi-CF4025M00012001_C7294570.pdf | !2151-RH100-25.000-13-F-0715-EXT-TR-NS1CT-ND | Huaxin | CF4025M00012001 | _ | -30+85°C | 10ppm
X81 | 1 | 12MHz_18pF | Celebi:xtal-3.2x2.5mm_4pin | https://datasheet.lcsc.com/lcsc/1912111437_TAE-Zhejiang-Abel-Elec-TAXM12M4RKDCDT2T_C403945.pdf | !2151-RH100-12.000-18-2020-EXT-TRCT-ND | TAE | TAXM12M4RKDCDT2T | _ | -40+85°C | 20ppm

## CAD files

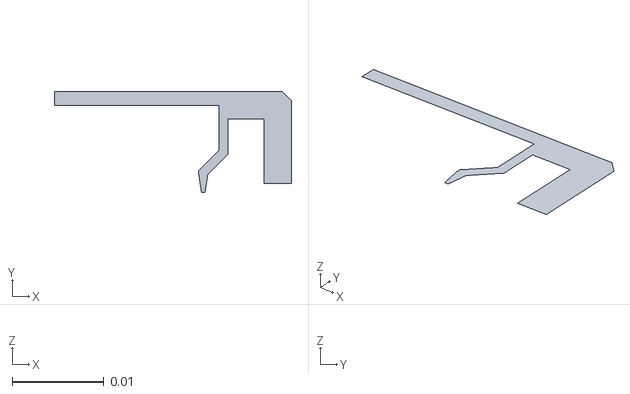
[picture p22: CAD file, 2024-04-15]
antenna/stl/ant.stl
0.0258 x 0.011 x 0

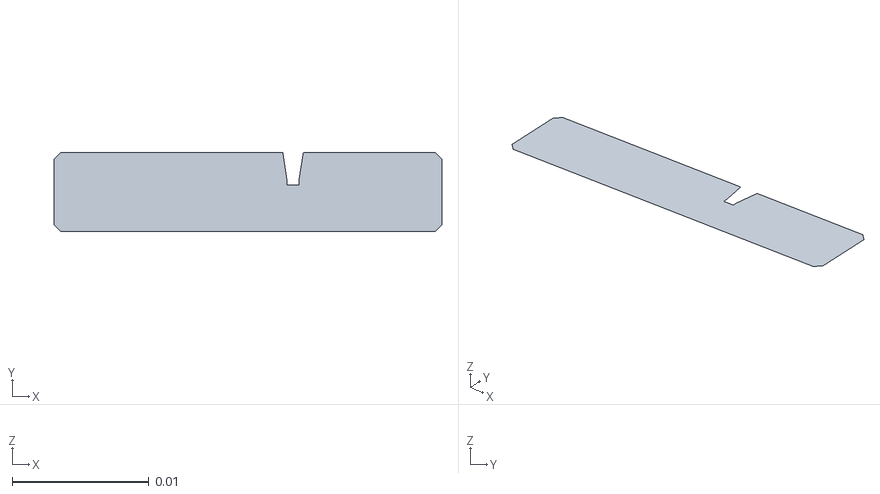
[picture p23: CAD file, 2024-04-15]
antenna/stl/tgndplane.stl
0.0284 x 0.0058 x 0

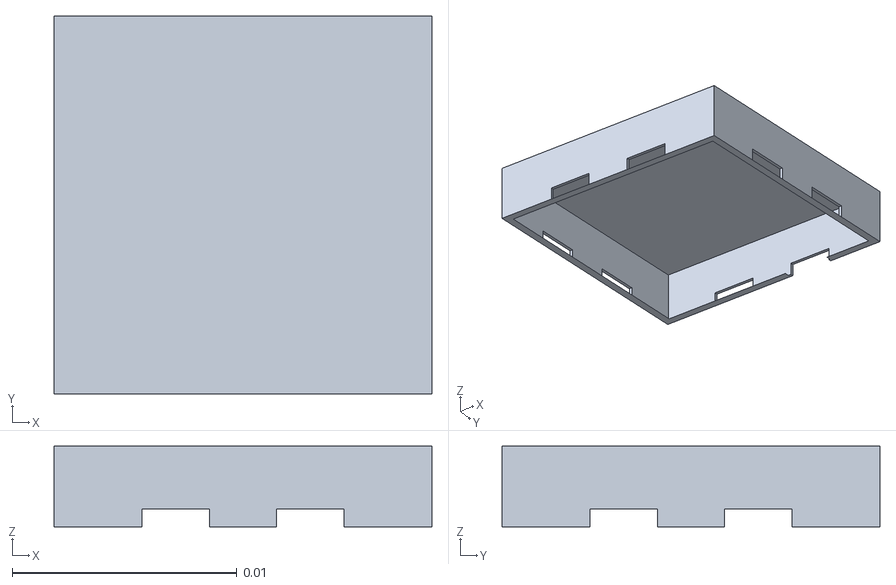
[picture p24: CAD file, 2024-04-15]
antenna/stl/shield.stl
0.0168 x 0.0168 x 0.0036

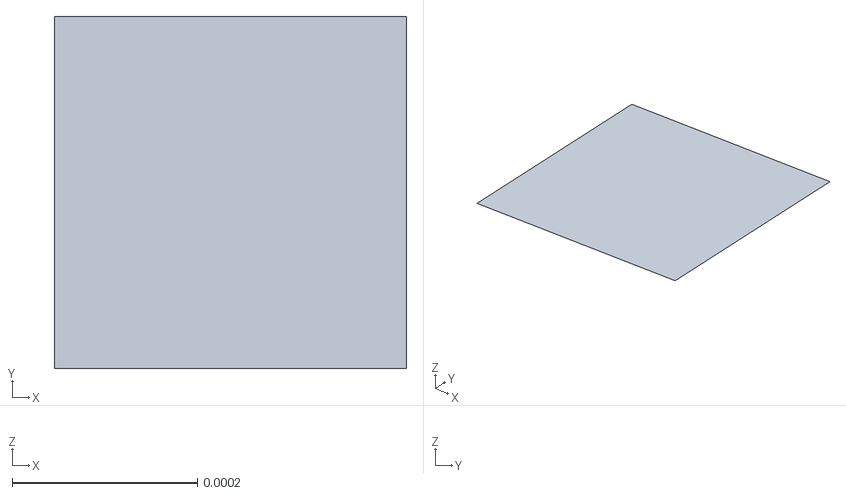
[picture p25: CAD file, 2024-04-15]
antenna/stl/port_resist_1.stl
0.00038 x 0.00038 x 0

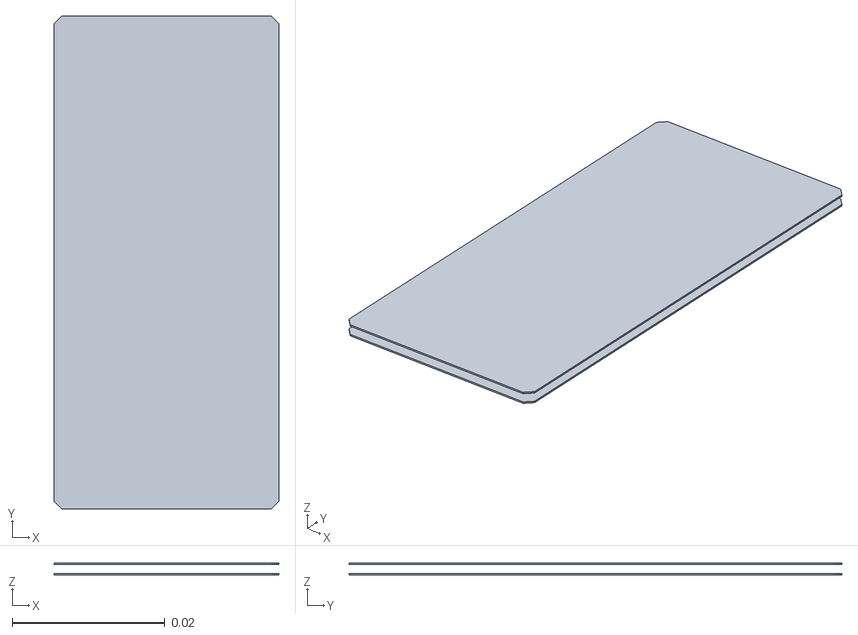
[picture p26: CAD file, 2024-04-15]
antenna/stl/sub_pp.stl
0.0295 x 0.0645 x 0.0016

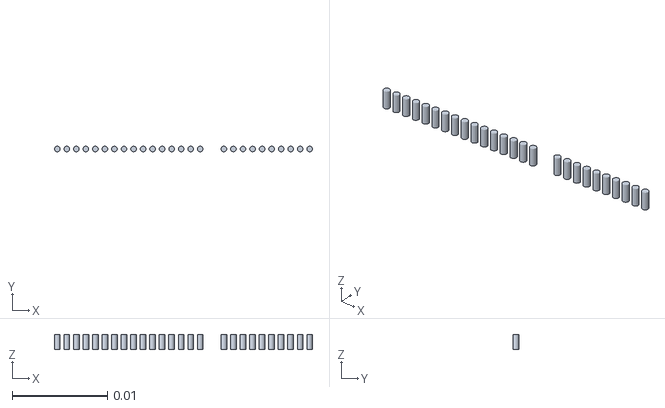
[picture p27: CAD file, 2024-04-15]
antenna/stl/via.stl
0.0271 x 0.0006 x 0.0016

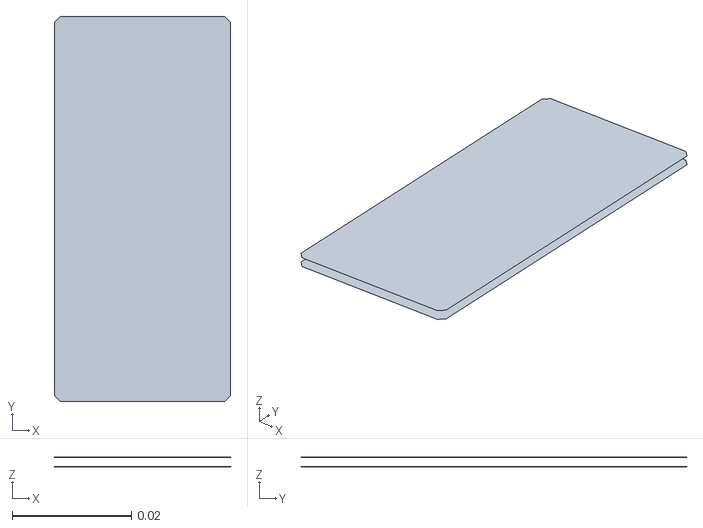
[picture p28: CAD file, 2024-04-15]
antenna/stl/mask.stl
0.0295 x 0.0645 x 0.00163

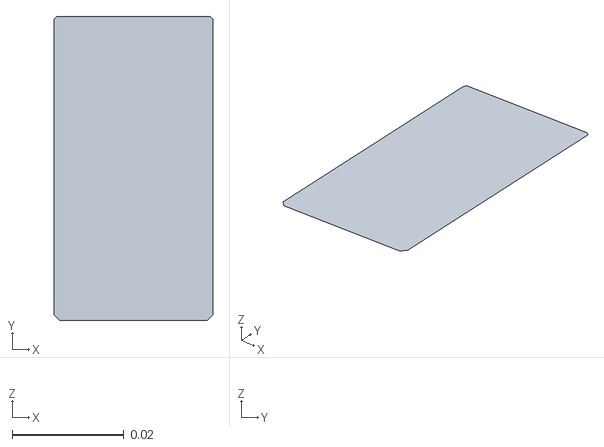
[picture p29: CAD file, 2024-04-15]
antenna/stl/i1gndplane.stl
0.0284 x 0.0543 x 0

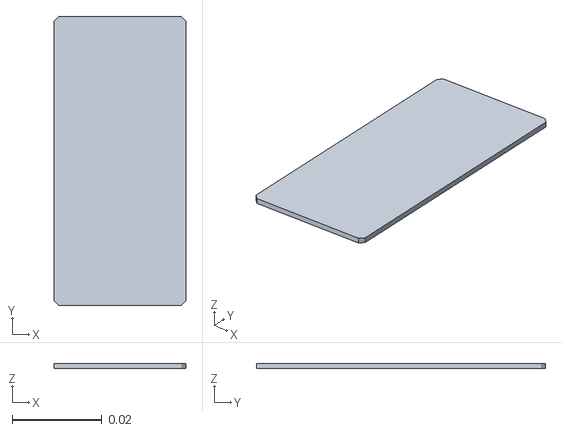
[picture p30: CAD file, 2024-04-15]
antenna/stl/sub_core.stl
0.0295 x 0.0645 x 0.00118

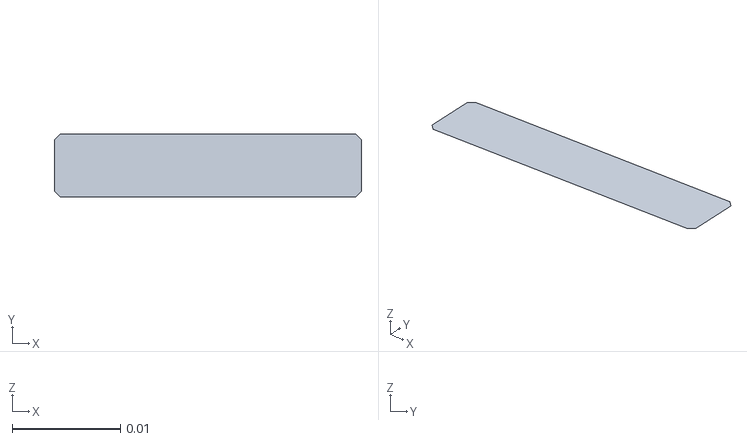
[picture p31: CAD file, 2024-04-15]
antenna/stl/bgndplane.stl
0.0284 x 0.0058 x 0

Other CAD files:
antenna/stl/i2gndplane.stl

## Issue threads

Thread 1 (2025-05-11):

Question: why no termination resistors before lan magnetics?

tomy983, 2025-05-11:
Hello, I was just wondering if the RTL8201F already include those, but cannot find any related documentation...
Thanks

selcukmustafa, 2025-05-27:
Hello,
Yes. I believe that they exist but not documented. I tried this on another board before this design. Not using them was okay. You may also refer to the second page of this document:
[https://docs.wiznet.io/img/products/w7500/w7500_rtl8201f_reference_sch.pdf](https://docs.wiznet.io/img/products/w7500/w7500_rtl8201f_reference_sch.pdf)

Closed 2025-05-28.

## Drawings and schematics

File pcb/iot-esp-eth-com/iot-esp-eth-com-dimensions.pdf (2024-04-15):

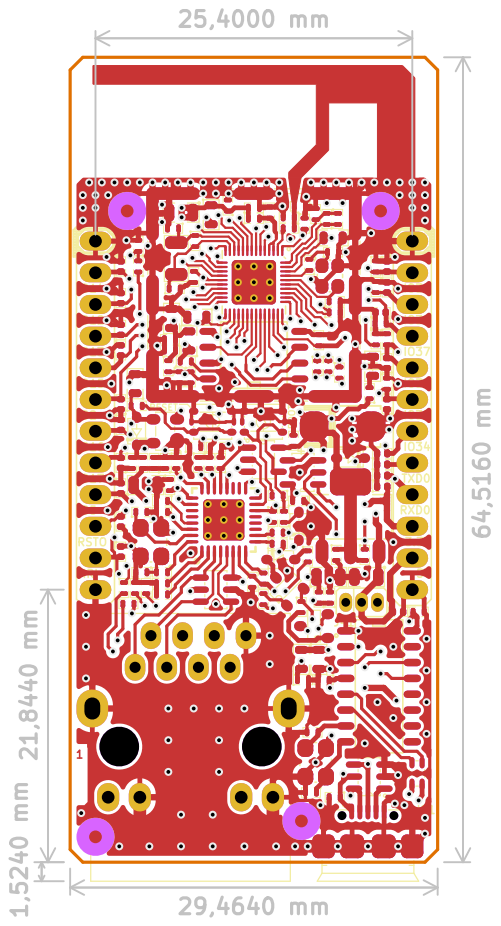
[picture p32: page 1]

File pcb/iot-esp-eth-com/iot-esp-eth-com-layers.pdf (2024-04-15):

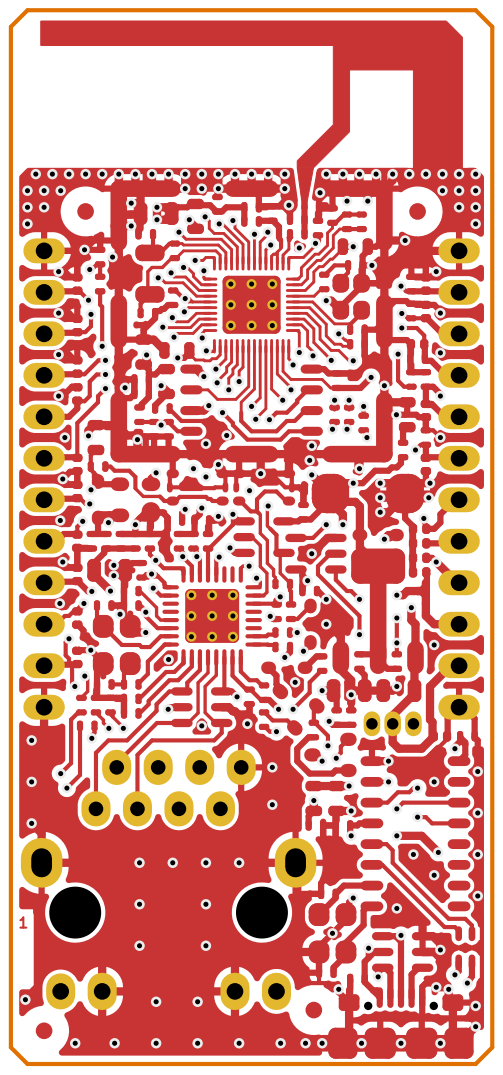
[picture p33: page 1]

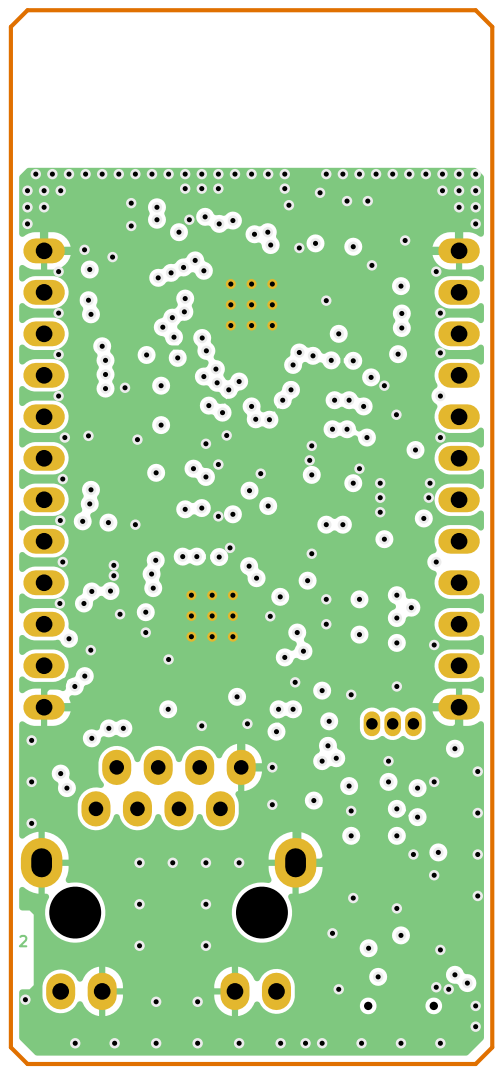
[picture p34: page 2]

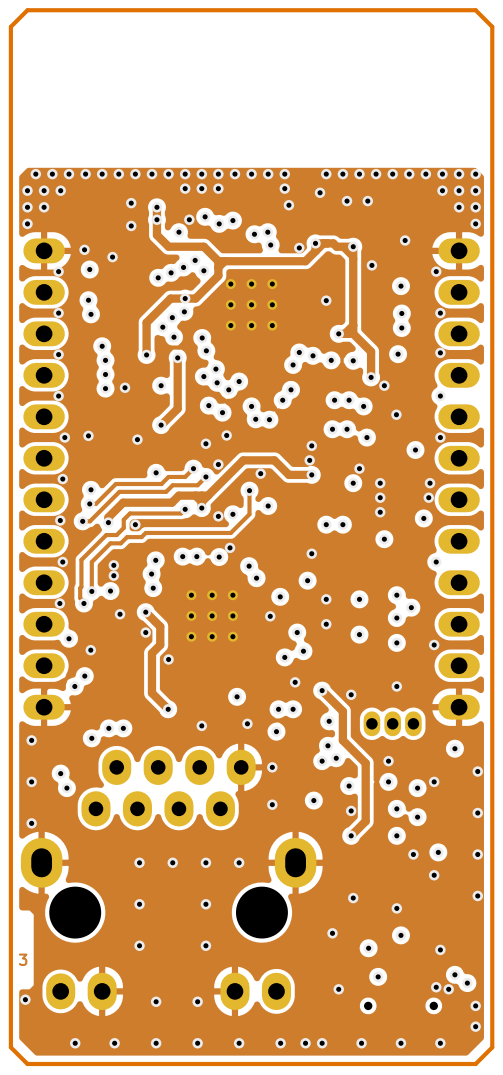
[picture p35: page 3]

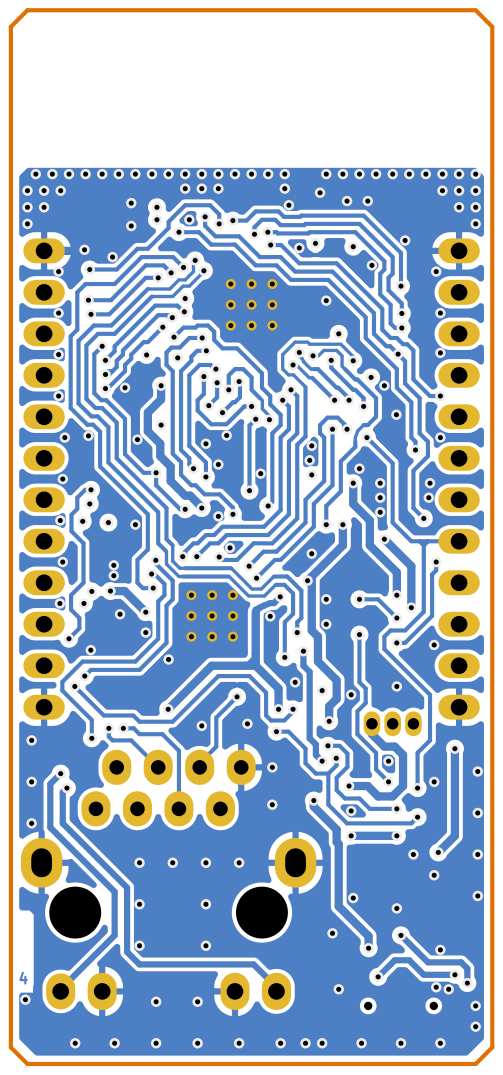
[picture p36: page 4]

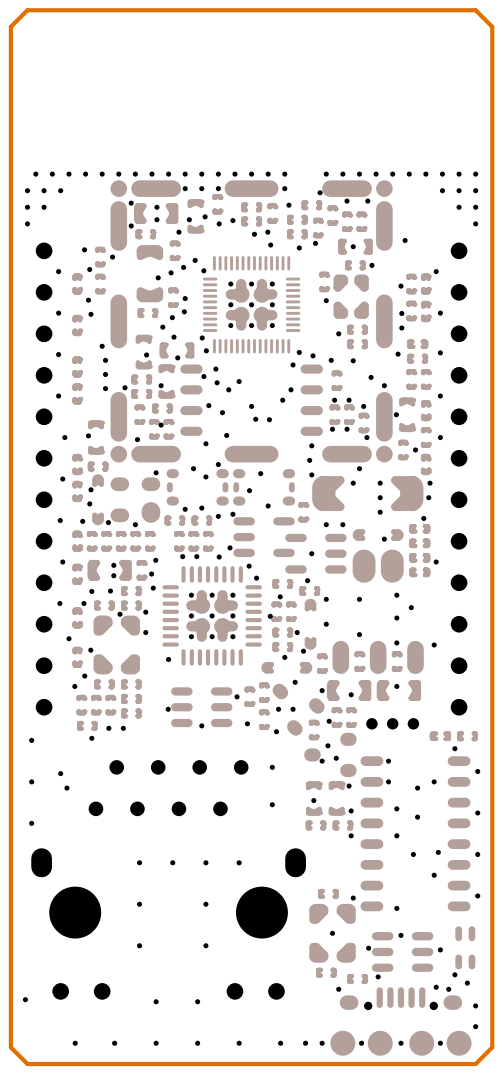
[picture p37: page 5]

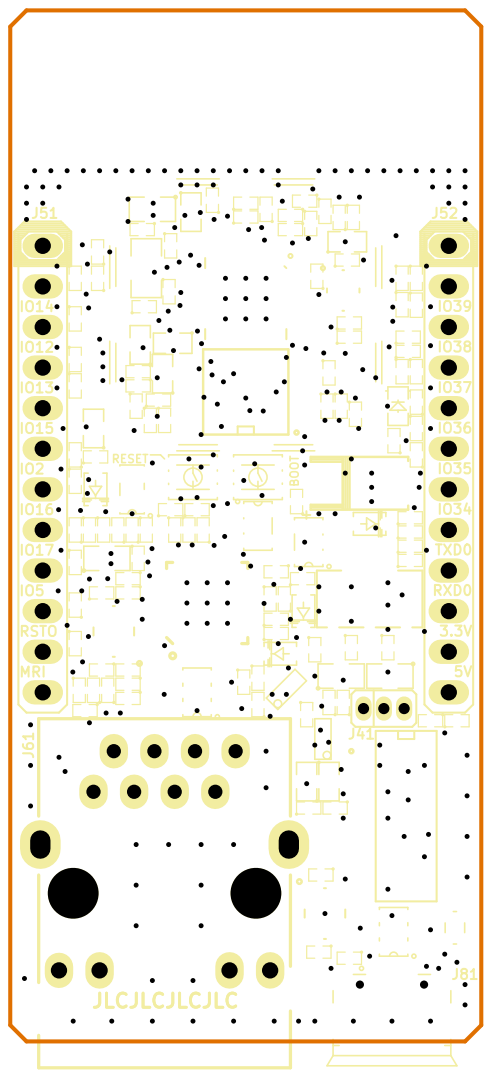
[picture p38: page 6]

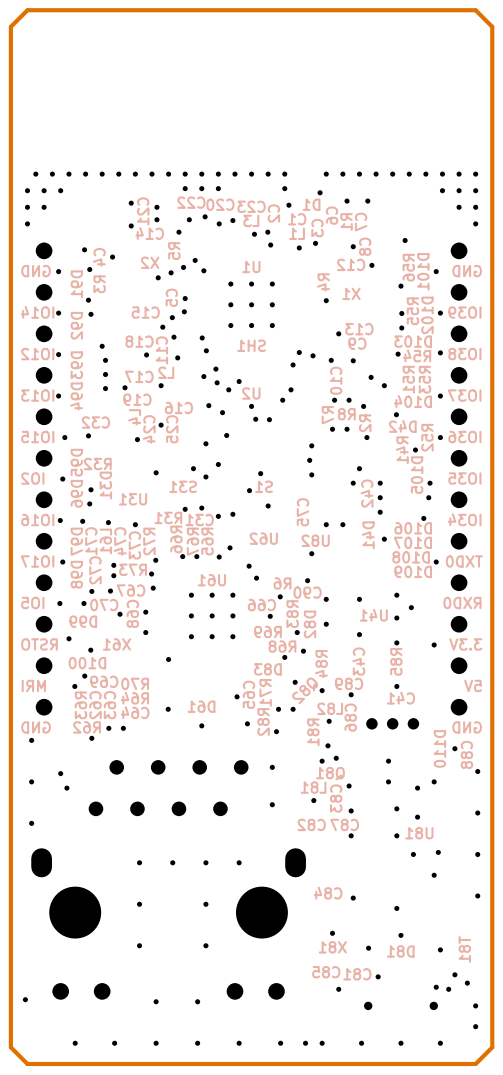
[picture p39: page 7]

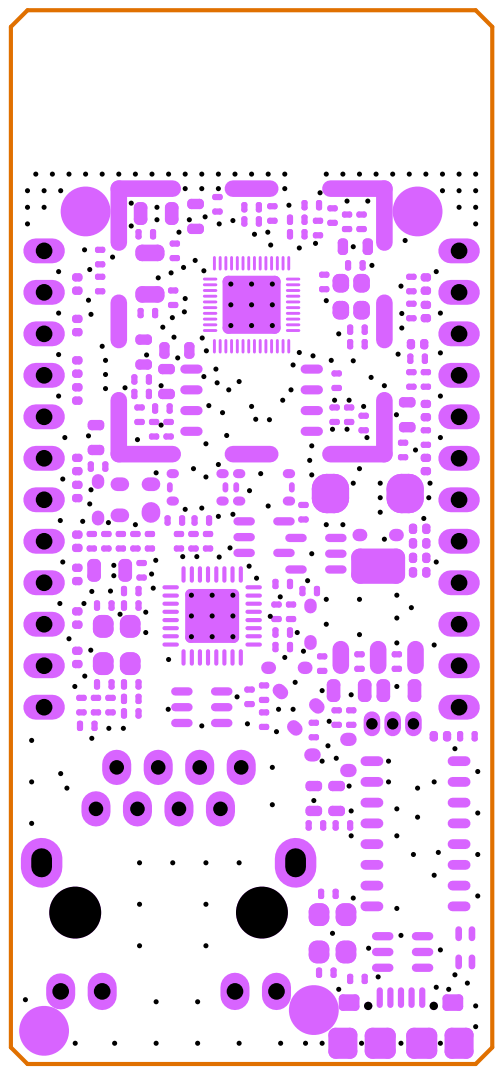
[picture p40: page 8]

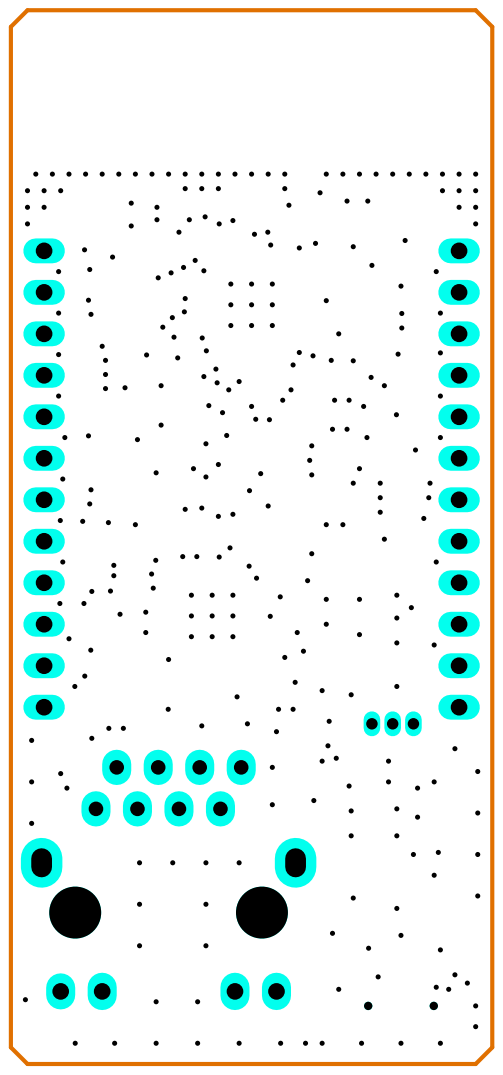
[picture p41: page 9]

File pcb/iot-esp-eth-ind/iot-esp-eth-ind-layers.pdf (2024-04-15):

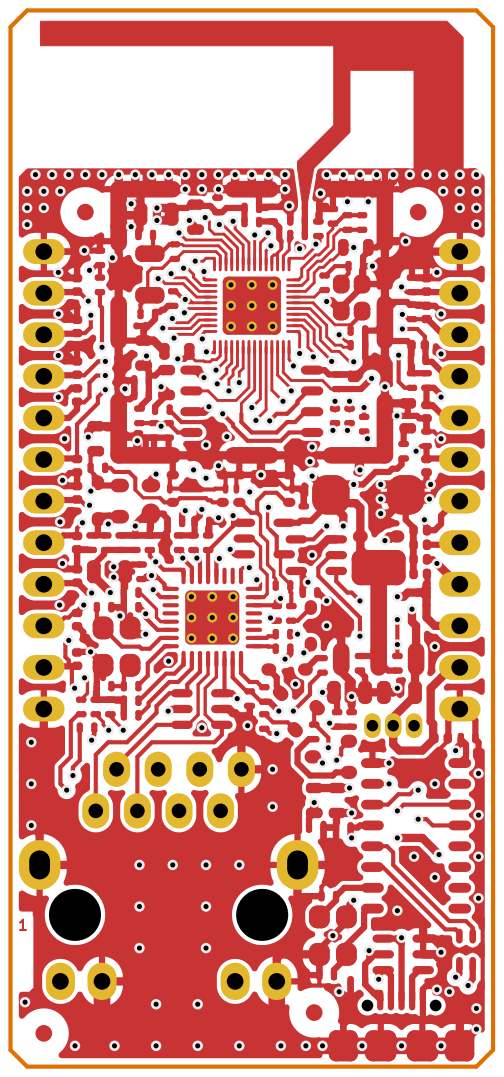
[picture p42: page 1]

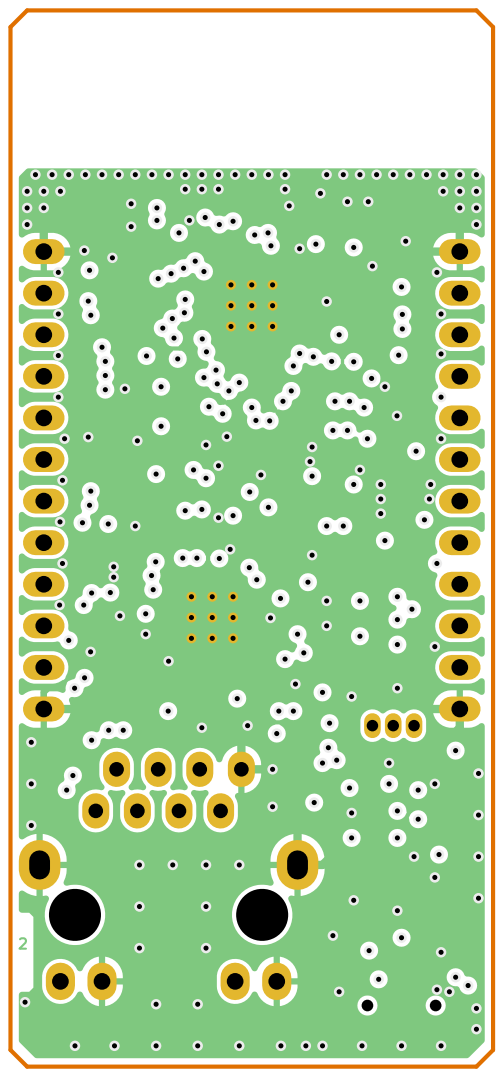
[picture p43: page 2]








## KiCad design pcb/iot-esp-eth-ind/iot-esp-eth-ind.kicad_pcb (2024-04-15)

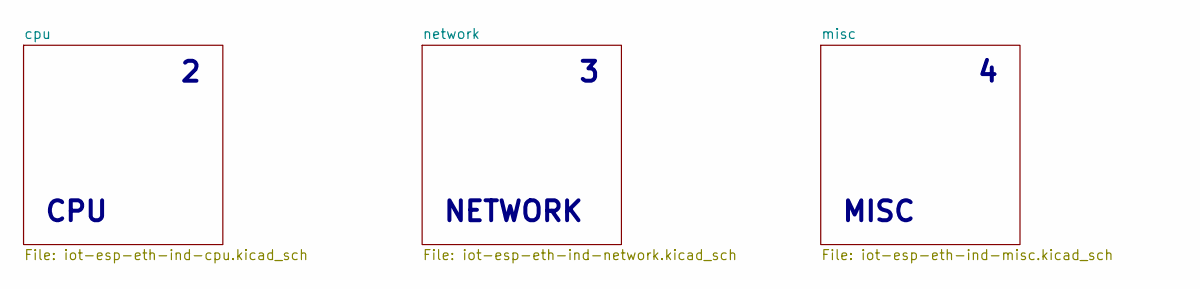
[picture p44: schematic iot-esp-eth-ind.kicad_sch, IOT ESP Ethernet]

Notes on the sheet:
NETWORK
MISC
CPU

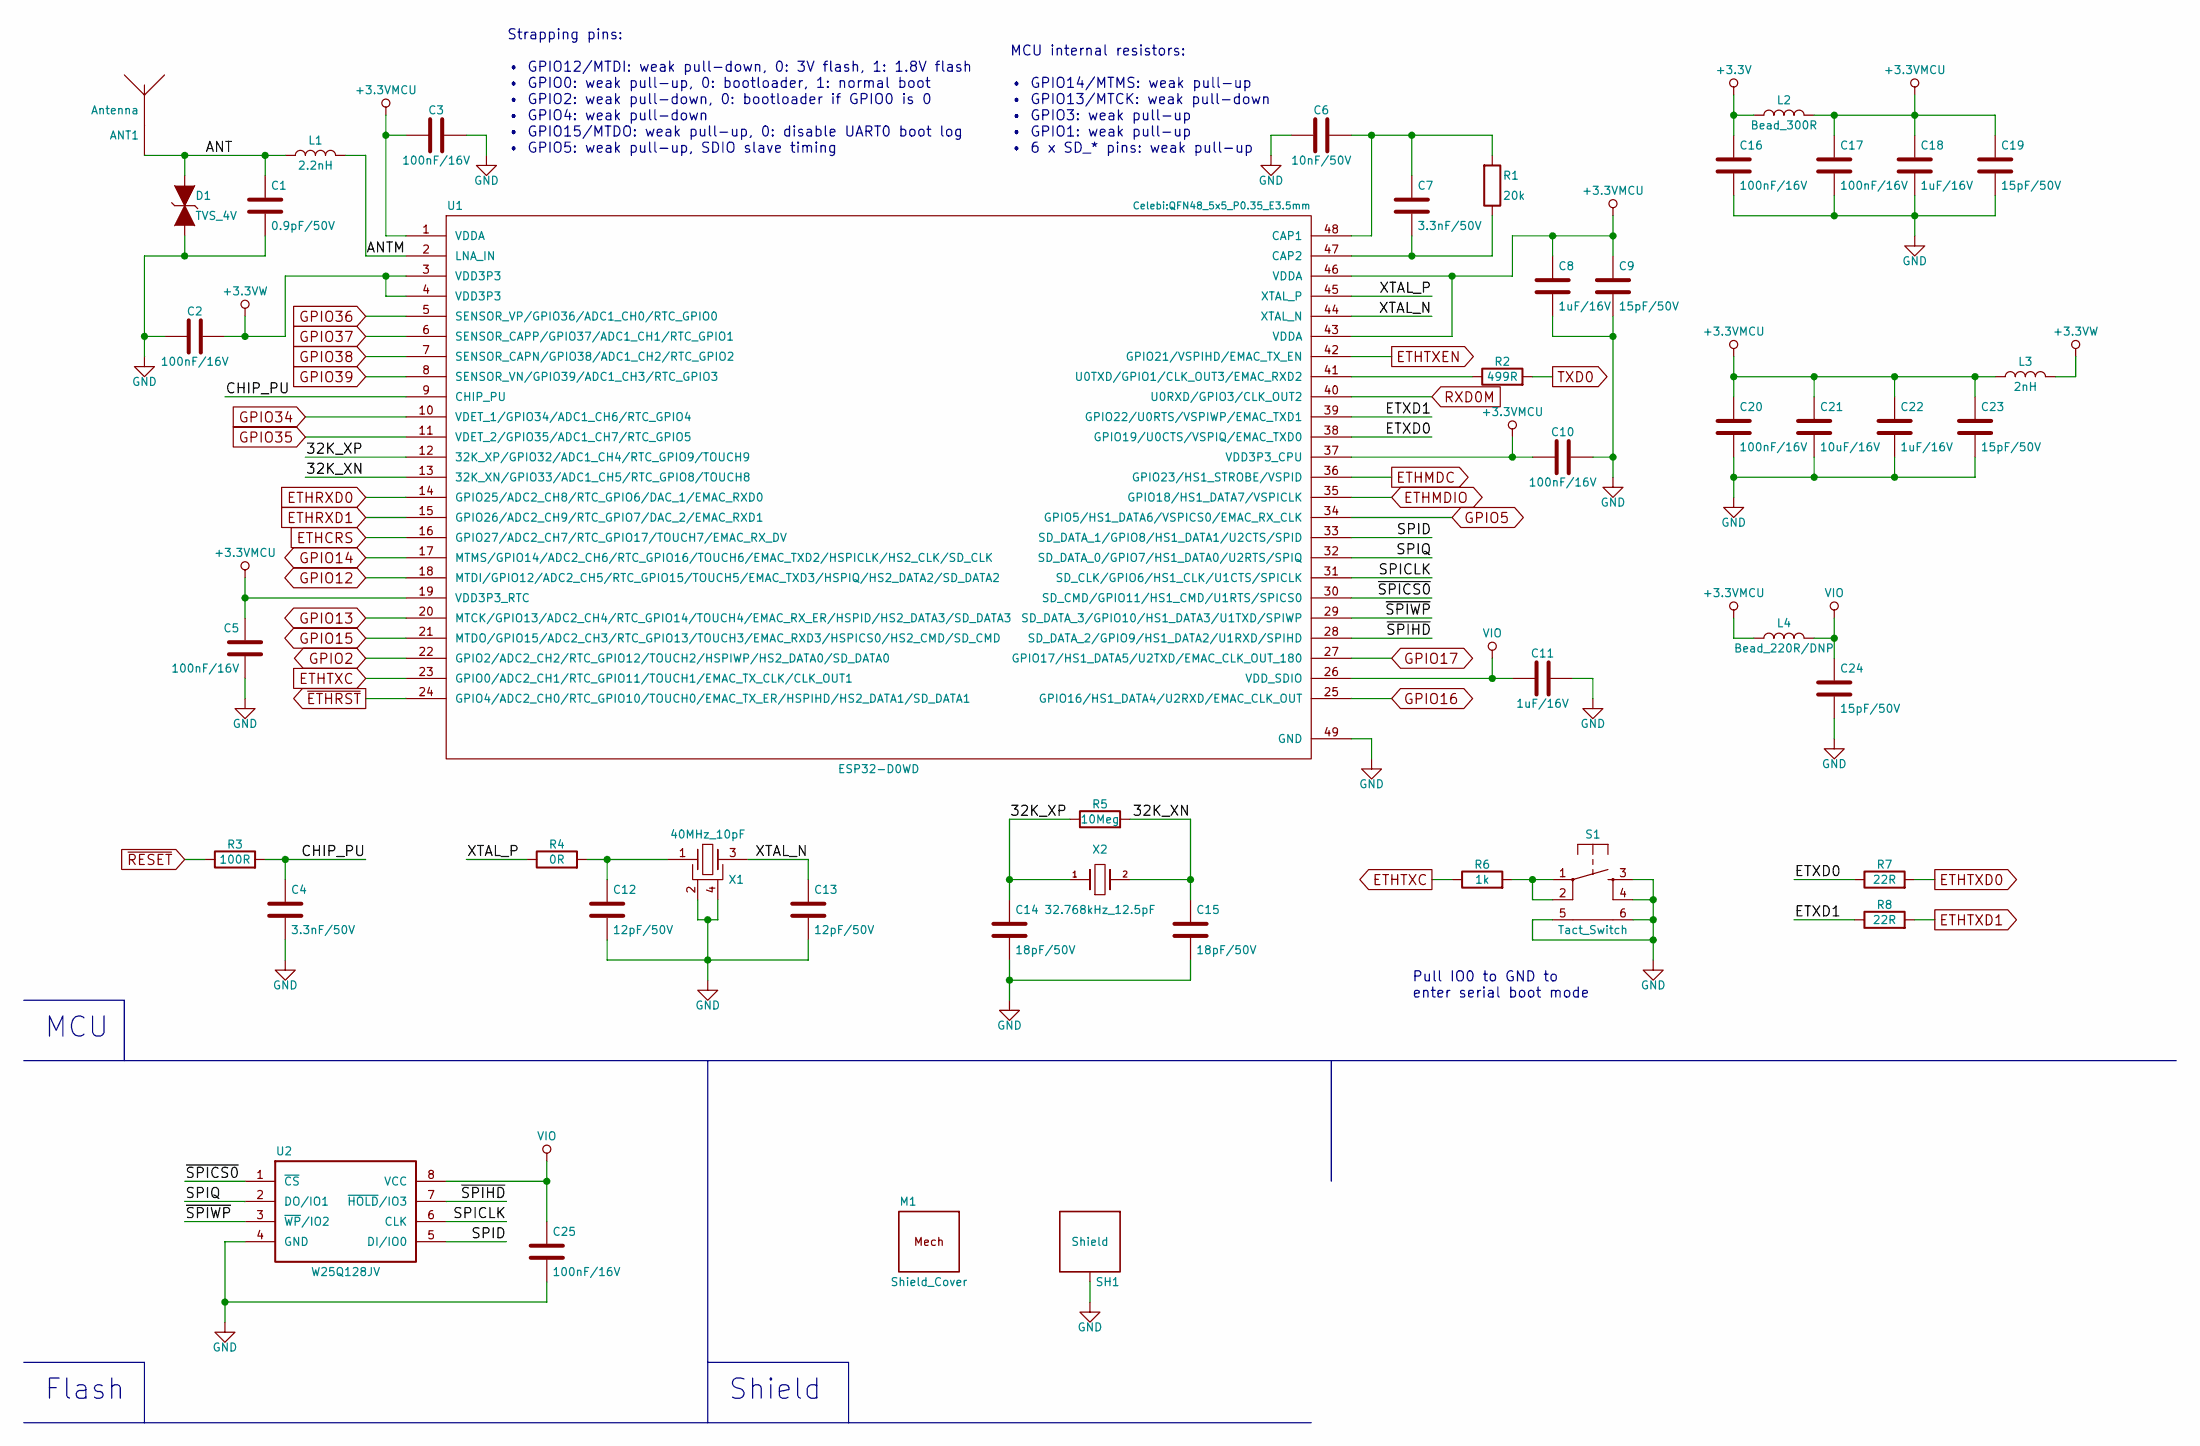
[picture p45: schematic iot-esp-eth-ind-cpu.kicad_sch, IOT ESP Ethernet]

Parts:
ANT1: Antenna; N.A.; Tolerance _; PartNumber _; Digikey _
C1: 0.9pF/50V; SM0402C; Tolerance 0.1pF; PartNumber 885392005022; Digikey !13-CC0402BRNPO9BNR90CT-ND
C2, C3, C5, C10, C16, C17, C20, C25: 100nF/16V; SM0402C; Tolerance 10%; PartNumber CL05B104KO5NNNC; Digikey 1276-1001-1-ND
C4, C7: 3.3nF/50V; SM0402C; Tolerance 10%; PartNumber CL05B332KB5NNNC; Digikey 1276-1552-1-ND
C6: 10nF/50V; SM0402C; Tolerance 10%; PartNumber CC0402KRX7R9BB103; Digikey 311-1349-1-ND
C8, C11, C18, C22: 1uF/16V; SM0603C; Tolerance 10%; PartNumber CC0603KRX7R7BB105; Digikey 311-1446-1-ND
C9, C19, C23, C24: 15pF/50V; SM0402C; Tolerance 5%; PartNumber CC0402JRNPO9BN150; Digikey 311-1017-1-ND
C12, C13: 12pF/50V; SM0402C; Tolerance 5%; PartNumber CC0402JRNPO9BN120; Digikey 311-1016-1-ND
C14, C15: 18pF/50V; SM0402C; Tolerance 5%; PartNumber CC0402JRNPO9BN180; Digikey 311-1415-1-ND
C21: 10uF/16V; SM0805C; Tolerance 10%; PartNumber CL21B106KOQNNNE; Digikey 1276-2872-1-ND
D1: TVS_4V; SM0402V; Tolerance _; PartNumber LXES15AAA1-153; Digikey 490-13210-2-ND
L1: 2.2nH; SM0402L; Tolerance 0.1nH; PartNumber 7447840022G; Digikey 732-7447840022GCT-ND
L2: Bead_300R; SM0603L; Tolerance 25%; PartNumber 742792641; Digikey 732-1592-1-ND
L3: 2nH; SM0402L; Tolerance 0.2nH; PartNumber 744765020A; Digikey 732-1705-1-ND
L4: Bead_220R/DNP; SM0402L; Tolerance 25%; PartNumber 742792780; Digikey 732-1569-1-ND
M1: Shield_Cover; N.A.; Tolerance _; PartNumber 36003160S; Digikey 732-11644-1-ND
R1: 20k; SM0402; Tolerance 1%; PartNumber RC0402FR-0720KL; Digikey 311-20.0KLRCT-ND
R2: 499R; SM0402; Tolerance 1%; PartNumber RC0402FR-07499RL; Digikey 311-499LRCT-ND
R3: 100R; SM0402; Tolerance 1%; PartNumber RC0402FR-07100RL; Digikey 311-100LRCT-ND
R4: 0R; SM0402; Tolerance Jumper; PartNumber RC0402JR-070RL; Digikey 311-0.0JRCT-ND
R5: 10Meg; SM0402; Tolerance 1%; PartNumber RC0402FR-0710ML; Digikey 311-10.0MLRCT-ND
R6: 1k; SM0402; Tolerance 1%; PartNumber RC0402FR-071KL; Digikey 311-1.00KLRCT-ND
R7, R8: 22R; SM0402; Tolerance 1%; PartNumber RC0402FR-0722RL; Digikey 311-22.0LRCT-ND
S1: Tact_Switch; switch-WE-WS-TASV-3x2.6_H1.4mm; Tolerance _; PartNumber 435171014816; Digikey 732-435171014816CT-ND
SH1: Shield; shield-36103166S; Tolerance _; PartNumber 36103166S; Digikey 732-11652-1-ND
U1: ESP32-D0WD; QFN48_5x5_P0.35_E3.5mm; Tolerance _; PartNumber ESP32-D0WD-V3; Digikey 1904-ESP32-D0WD-V3CT-ND
U2: W25Q128JV; SO8_5.2x5.2_P1.27mm; Tolerance _; PartNumber W25Q128JVSIQ; Digikey W25Q128JVSIQ-ND
X1: 40MHz_10pF; xtal-2.5x2.0mm_4pin; Tolerance 10ppm; PartNumber R2520-40.000-10-F-1010-EXT-TR; Digikey 2151-R2520-40.000-10-F-1010-EXT-TRCT-ND
X2: 32.768kHz_12.5pF; xtal-3.2x1.5mm; Tolerance 10ppm; PartNumber RT3215-32.768-12.5-TR-10PPM; Digikey 2151-RT3215-32.768-12.5-TR-10PPMCT-ND

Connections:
+3.3V: C16.1, L2.1; also elsewhere on the board
+3.3VMCU: C3.2, C5.1, C8.1, C9.1, C10.2, C17.1, C18.1, C19.1, C20.1, C21.1, C22.1, C23.1, L2.2, L3.1, L4.1, U1.1 (VDDA), U1.19 (VDD3P3_RTC), U1.37 (VDD3P3_CPU), U1.43 (VDDA), U1.46 (VDDA)
+3.3VW: C2.1, L3.2, U1.3 (VDD3P3), U1.4 (VDD3P3)
/cpu/32K_XN: C15.1, R5.2, U1.13 (32K_XN/GPIO33/ADC1_CH5/RTC_GPIO8/TOUCH8), X2.2 (B)
/cpu/32K_XP: C14.1, R5.1, U1.12 (32K_XP/GPIO32/ADC1_CH4/RTC_GPIO9/TOUCH9), X2.1 (A)
/cpu/ANT: ANT1.1, C1.1, D1.2 (A), L1.1
/cpu/ANTM: L1.2, U1.2 (LNA_IN)
/cpu/CHIP_PU: C4.1, R3.2, U1.9 (CHIP_PU)
/cpu/ETXD0: R7.1, U1.38 (GPIO19/U0CTS/VSPIQ/EMAC_TXD0)
/cpu/ETXD1: R8.1, U1.39 (GPIO22/U0RTS/VSPIWP/EMAC_TXD1)
/cpu/SPICLK: U1.31 (SD_CLK/GPIO6/HS1_CLK/U1CTS/SPICLK), U2.6 (CLK)
/cpu/SPID: U1.33 (SD_DATA_1/GPIO8/HS1_DATA1/U2CTS/SPID), U2.5 (DI/IO0)
/cpu/SPIQ: U1.32 (SD_DATA_0/GPIO7/HS1_DATA0/U2RTS/SPIQ), U2.2 (DO/IO1)
/cpu/XTAL_N: C13.1, U1.44 (XTAL_N), X1.3 (B)
/cpu/XTAL_P: R4.1, U1.45 (XTAL_P)
/cpu/~SPICS0: U1.30 (SD_CMD/GPIO11/HS1_CMD/U1RTS/SPICS0), U2.1 (~CS)
/cpu/~SPIHD: U1.28 (SD_DATA_2/GPIO9/HS1_DATA2/U1RXD/SPIHD), U2.7 (~HOLD/IO3)
/cpu/~SPIWP: U1.29 (SD_DATA_3/GPIO10/HS1_DATA3/U1TXD/SPIWP), U2.3 (~WP/IO2)
ETHCRS: U1.16 (GPIO27/ADC2_CH7/RTC_GPIO17/TOUCH7/EMAC_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); also elsewhere on the board
ETHMDC: U1.36 (GPIO23/HS1_STROBE/VSPID); also elsewhere on the board
ETHMDIO: U1.35 (GPIO18/HS1_DATA7/VSPICLK); also elsewhere on the board
ETHRXD0: U1.14 (GPIO25/ADC2_CH8/RTC_GPIO6/DAC_1/EMAC_RX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); also elsewhere on the board
ETHRXD1: U1.15 (GPIO26/ADC2_CH9/RTC_GPIO7/DAC_2/EMAC_RX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); also elsewhere on the board
ETHTXC: R6.1, U1.23 (GPIO0/ADC2_CH1/RTC_GPIO11/TOUCH1/EMAC_T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); also elsewhere on the board
ETHTXD0: R7.2; also elsewhere on the board
ETHTXD1: R8.2; also elsewhere on the board
ETHTXEN: U1.42 (GPIO21/VSPIHD/EMAC_TX_EN); also elsewhere on the board
GND: C1.2, C2.2, C3.1, C4.2, C5.2, C6.1, C8.2, C9.2, C10.1, C11.2, C12.2, C13.2, C14.2, C15.2, C16.2, C17.2, C18.2, C19.2, C20.2, C21.2, C22.2, C23.2, C24.2, C25.2, D1.1 (A), S1.3, S1.4, S1.5, S1.6, SH1.1 (GND), U1.49 (GND), U2.4 (GND), X1.2 (GND), X1.4 (GND); also elsewhere on the board
GPIO2: U1.22 (GPIO2/ADC2_CH2/RTC_GPIO12/TOUCH2/HSPIWP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); also elsewhere on the board
GPIO5: U1.34 (GPIO5/HS1_DATA6/VSPICS0/EMAC_RX_CLK); also elsewhere on the board
GPIO12: U1.18 (MTDI/GPIO12/ADC2_CH5/RTC_GPIO15/TOUCH5/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); also elsewhere on the board
GPIO13: U1.20 (MTCK/GPIO13/ADC2_CH4/RTC_GPIO14/TOUCH4/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); also elsewhere on the board
GPIO14: U1.17 (MTMS/GPIO14/ADC2_CH6/RTC_GPIO16/TOUCH6/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); also elsewhere on the board
GPIO15: U1.21 (MTDO/GPIO15/ADC2_CH3/RTC_GPIO13/TOUCH3/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); also elsewhere on the board
GPIO16: U1.25 (GPIO16/HS1_DATA4/U2RXD/EMAC_CLK_OUT); also elsewhere on the board
GPIO17: U1.27 (GPIO17/HS1_DATA5/U2TXD/EMAC_CLK_OUT_180); also elsewhere on the board
GPIO34: U1.10 (VDET_1/GPIO34/ADC1_CH6/RTC_GPIO4); also elsewhere on the board
GPIO35: U1.11 (VDET_2/GPIO35/ADC1_CH7/RTC_GPIO5); also elsewhere on the board
GPIO36: U1.5 (SENSOR_VP/GPIO36/ADC1_CH0/RTC_GPIO0); also elsewhere on the board
GPIO37: U1.6 (SENSOR_CAPP/GPIO37/ADC1_CH1/RTC_GPIO1); also elsewhere on the board
GPIO38: U1.7 (SENSOR_CAPN/GPIO38/ADC1_CH2/RTC_GPIO2); also elsewhere on the board
GPIO39: U1.8 (SENSOR_VN/GPIO39/ADC1_CH3/RTC_GPIO3); also elsewhere on the board
unnamed: C6.2, C7.1, R1.2, U1.48 (CAP1)
unnamed: C7.2, R1.1, U1.47 (CAP2)
unnamed: C12.1, R4.2, X1.1 (A)
unnamed: R2.1, U1.41 (U0TXD/GPIO1/CLK_OUT3/EMAC_RXD2)
unnamed: R6.2, S1.1, S1.2
RXD0M: U1.40 (U0RXD/GPIO3/CLK_OUT2); also elsewhere on the board
TXD0: R2.2; also elsewhere on the board
VIO: C11.1, C24.1, C25.1, L4.2, U1.26 (VDD_SDIO), U2.8 (VCC)
~ETHRST: U1.24 (GPIO4/ADC2_CH0/RTC_GPIO10/TOUCH0/EMAC_T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); also elsewhere on the board
~RESET: R3.1; also elsewhere on the board

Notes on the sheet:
MCU internal resistors: • GPIO14/MTMS: weak pull-up • GPIO13/MTCK: weak pull-down • GPIO3: weak pull-up • GPIO1: weak pull-up • 6 x SD_* pins: weak pull-up
Shield
Flash
MCU
Strapping pins: • GPIO12/MTDI: weak pull-down, 0: 3V flash, 1: 1.8V flash • GPIO0: weak pull-up, 0: bootloader, 1: normal boot • GPIO2: weak pull-down, 0: bootloader if GPIO0 is 0 • GPIO4: weak pull-down • GPIO15/MTDO: weak pull-up, 0: disable UART0 boot log • GPIO5: weak pull-up, SDIO slave timing
Pull IO0 to GND to enter serial boot mode

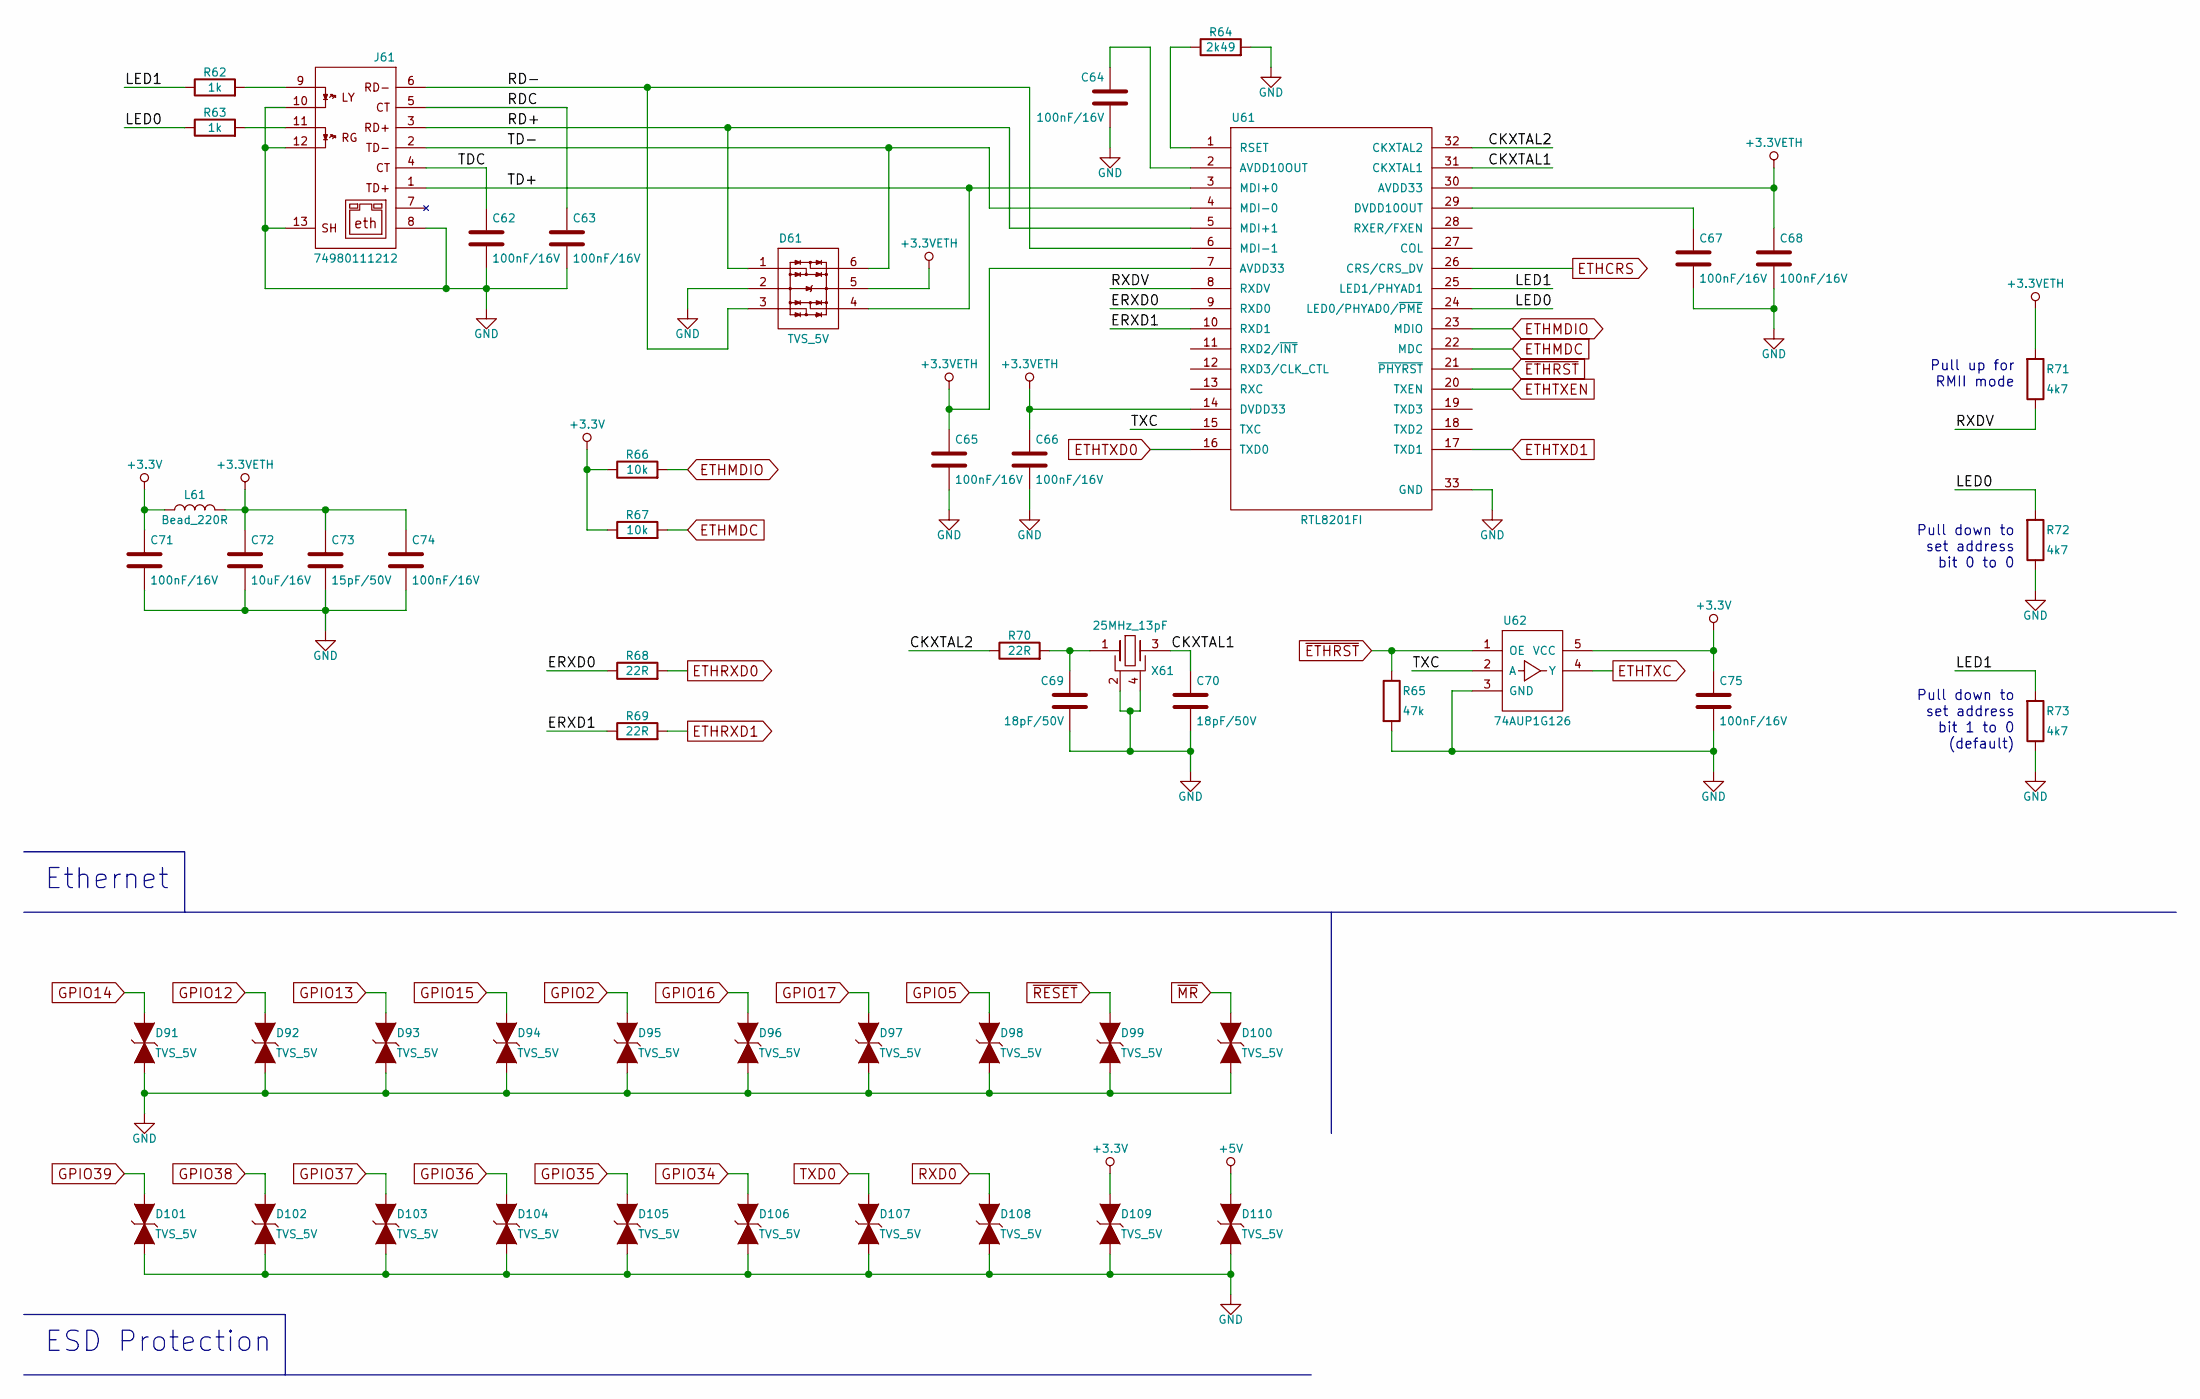
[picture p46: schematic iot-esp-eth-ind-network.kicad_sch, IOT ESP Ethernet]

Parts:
C62, C63, C64, C65, C66, C67, C68, C71, C74, C75: 100nF/16V; SM0402C; Tolerance 10%; PartNumber CL05B104KO5NNNC; Digikey 1276-1001-1-ND
C69, C70: 18pF/50V; SM0402C; Tolerance 5%; PartNumber CC0402JRNPO9BN180; Digikey 311-1415-1-ND
C72: 10uF/16V; SM0805C; Tolerance 10%; PartNumber CL21B106KOQNNNE; Digikey 1276-2872-1-ND
C73: 15pF/50V; SM0402C; Tolerance 5%; PartNumber CC0402JRNPO9BN150; Digikey 311-1017-1-ND
D61: TVS_5V; SOT23-6L; Tolerance _; PartNumber 824015; Digikey 732-4467-1-ND
D91, D92, D93, D94, D95, D96, D97, D98, D99, D100, D101, D102, D103, D104, D105, D106, D107, D108, D109, D110: TVS_5V; DFN1006-2; Tolerance _; PartNumber ULC0511CDN; Digikey !490-12804-1-ND
J61: 74980111212; eth-74980111212; Tolerance _; PartNumber 74980111212; Digikey _
L61: Bead_220R; SM0402L; Tolerance 25%; PartNumber 742792780; Digikey 732-1569-1-ND
R62, R63: 1k; SM0402; Tolerance 1%; PartNumber RC0402FR-071KL; Digikey 311-1.00KLRCT-ND
R64: 2k49; SM0402; Tolerance 1%; PartNumber RC0402FR-072K49L; Digikey 311-2.49KLRCT-ND
R65: 47k; SM0402; Tolerance 1%; PartNumber RC0402FR-0747KL; Digikey 311-47.0KLRCT-ND
R66, R67: 10k; SM0402; Tolerance 1%; PartNumber RC0402FR-0710KL; Digikey 311-10.0KLRCT-ND
R68, R69, R70: 22R; SM0402; Tolerance 1%; PartNumber RC0402FR-0722RL; Digikey 311-22.0LRCT-ND
R71, R72, R73: 4k7; SM0402; Tolerance 1%; PartNumber RC0402FR-074K7L; Digikey 311-4.7KLRCT-ND
U61: RTL8201FI; QFN32_5x5_P0.5_E3.35mm; Tolerance _; PartNumber RTL8201FI-VC-CG; Digikey _
U62: 74AUP1G126; SOT23-5L; Tolerance _; PartNumber SN74AUP1G126DBVR; Digikey 296-18005-1-ND
X61: 25MHz_13pF; xtal-3.2x2.5mm_4pin; Tolerance 7ppm; PartNumber RH100-25.000-13-F-0715-EXT-TR-NS1; Digikey 2151-RH100-25.000-13-F-0715-EXT-TR-NS1C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

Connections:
+3.3V: C71.1, C75.1, D109.2 (A), L61.1, R66.1, R67.1, U62.5 (VCC); also elsewhere on the board
+3.3VETH: C65.1, C66.1, C68.1, C72.1, C73.1, C74.1, D61.5 (VDD), L61.2, R71.2, U61.7 (AVDD33), U61.14 (DVDD33), U61.30 (AVDD33)
+5V: D110.2 (A); also elsewhere on the board
/network/CKXTAL1: C70.1, U61.31 (CKXTAL1), X61.3 (B)
/network/CKXTAL2: R70.1, U61.32 (CKXTAL2)
/network/ERXD0: R68.1, U61.9 (RXD0)
/network/ERXD1: R69.1, U61.10 (RXD1)
/network/LED0: R63.1, R72.2, U61.24 (LED0/PHYAD0/~PME)
/network/LED1: R62.1, R73.2, U61.25 (LED1/PHYAD1)
/network/RD+: D61.1 (IO1), J61.3 (RD+), U61.5 (MDI+1)
/network/RD-: D61.3 (IO2), J61.6 (RD-), U61.6 (MDI-1)
/network/RDC: C63.1, J61.5 (CT)
/network/RXDV: R71.1, U61.8 (RXDV)
/network/TD+: D61.4 (IO3), J61.1 (TD+), U61.3 (MDI+0)
/network/TD-: D61.6 (IO4), J61.2 (TD-), U61.4 (MDI-0)
/network/TDC: C62.1, J61.4 (CT)
/network/TXC: U61.15 (TXC), U62.2 (A)
ETHCRS: U61.26 (CRS/CRS_DV); also elsewhere on the board
ETHMDC: R67.2, U61.22 (MDC); also elsewhere on the board
ETHMDIO: R66.2, U61.23 (MDIO); also elsewhere on the board
ETHRXD0: R68.2; also elsewhere on the board
ETHRXD1: R69.2; also elsewhere on the board
ETHTXC: U62.4 (Y); also elsewhere on the board
ETHTXD0: U61.16 (TXD0); also elsewhere on the board
ETHTXD1: U61.17 (TXD1); also elsewhere on the board
ETHTXEN: U61.20 (TXEN); also elsewhere on the board
GND: C62.2, C63.2, C64.2, C65.2, C66.2, C67.2, C68.2, C69.2, C70.2, C71.2, C72.2, C73.2, C74.2, C75.2, D61.2 (GND), D91.1 (A), D92.1 (A), D93.1 (A), D94.1 (A), D95.1 (A), D96.1 (A), D97.1 (A), D98.1 (A), D99.1 (A), D100.1 (A), D101.1 (A), D102.1 (A), D103.1 (A), D104.1 (A), D105.1 (A), D106.1 (A), D107.1 (A), D108.1 (A), D109.1 (A), D110.1 (A), J61.8 (GND), J61.10 (LED1-), J61.12 (LED2+), J61.13 (SHIELD), R64.2, R65.2, R72.1, R73.1, U61.33 (GND), U62.3 (GND), X61.2 (GND), X61.4 (GND); also elsewhere on the board
GPIO2: D95.2 (A); also elsewhere on the board
GPIO5: D98.2 (A); also elsewhere on the board
GPIO12: D92.2 (A); also elsewhere on the board
GPIO13: D93.2 (A); also elsewhere on the board
GPIO14: D91.2 (A); also elsewhere on the board
GPIO15: D94.2 (A); also elsewhere on the board
GPIO16: D96.2 (A); also elsewhere on the board
GPIO17: D97.2 (A); also elsewhere on the board
GPIO34: D106.2 (A); also elsewhere on the board
GPIO35: D105.2 (A); also elsewhere on the board
GPIO36: D104.2 (A); also elsewhere on the board
GPIO37: D103.2 (A); also elsewhere on the board
GPIO38: D102.2 (A); also elsewhere on the board
GPIO39: D101.2 (A); also elsewhere on the board
unnamed: C64.1, U61.2 (AVDD10OUT)
unnamed: C67.1, U61.29 (DVDD10OUT)
unnamed: C69.1, R70.2, X61.1 (A)
unnamed: J61.9 (LED1+), R62.2
unnamed: J61.11 (LED2-), R63.2
unnamed: R64.1, U61.1 (RSET)
RXD0: D108.2 (A); also elsewhere on the board
TXD0: D107.2 (A); also elsewhere on the board
~ETHRST: R65.1, U61.21 (~PHYRST), U62.1 (OE); also elsewhere on the board
~MR: D100.2 (A); also elsewhere on the board
~RESET: D99.2 (A); also elsewhere on the board

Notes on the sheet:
ESD Protection
Pull down to set address bit 0 to 0
Pull down to set address bit 1 to 0 (default)
Pull up for RMII mode
Ethernet

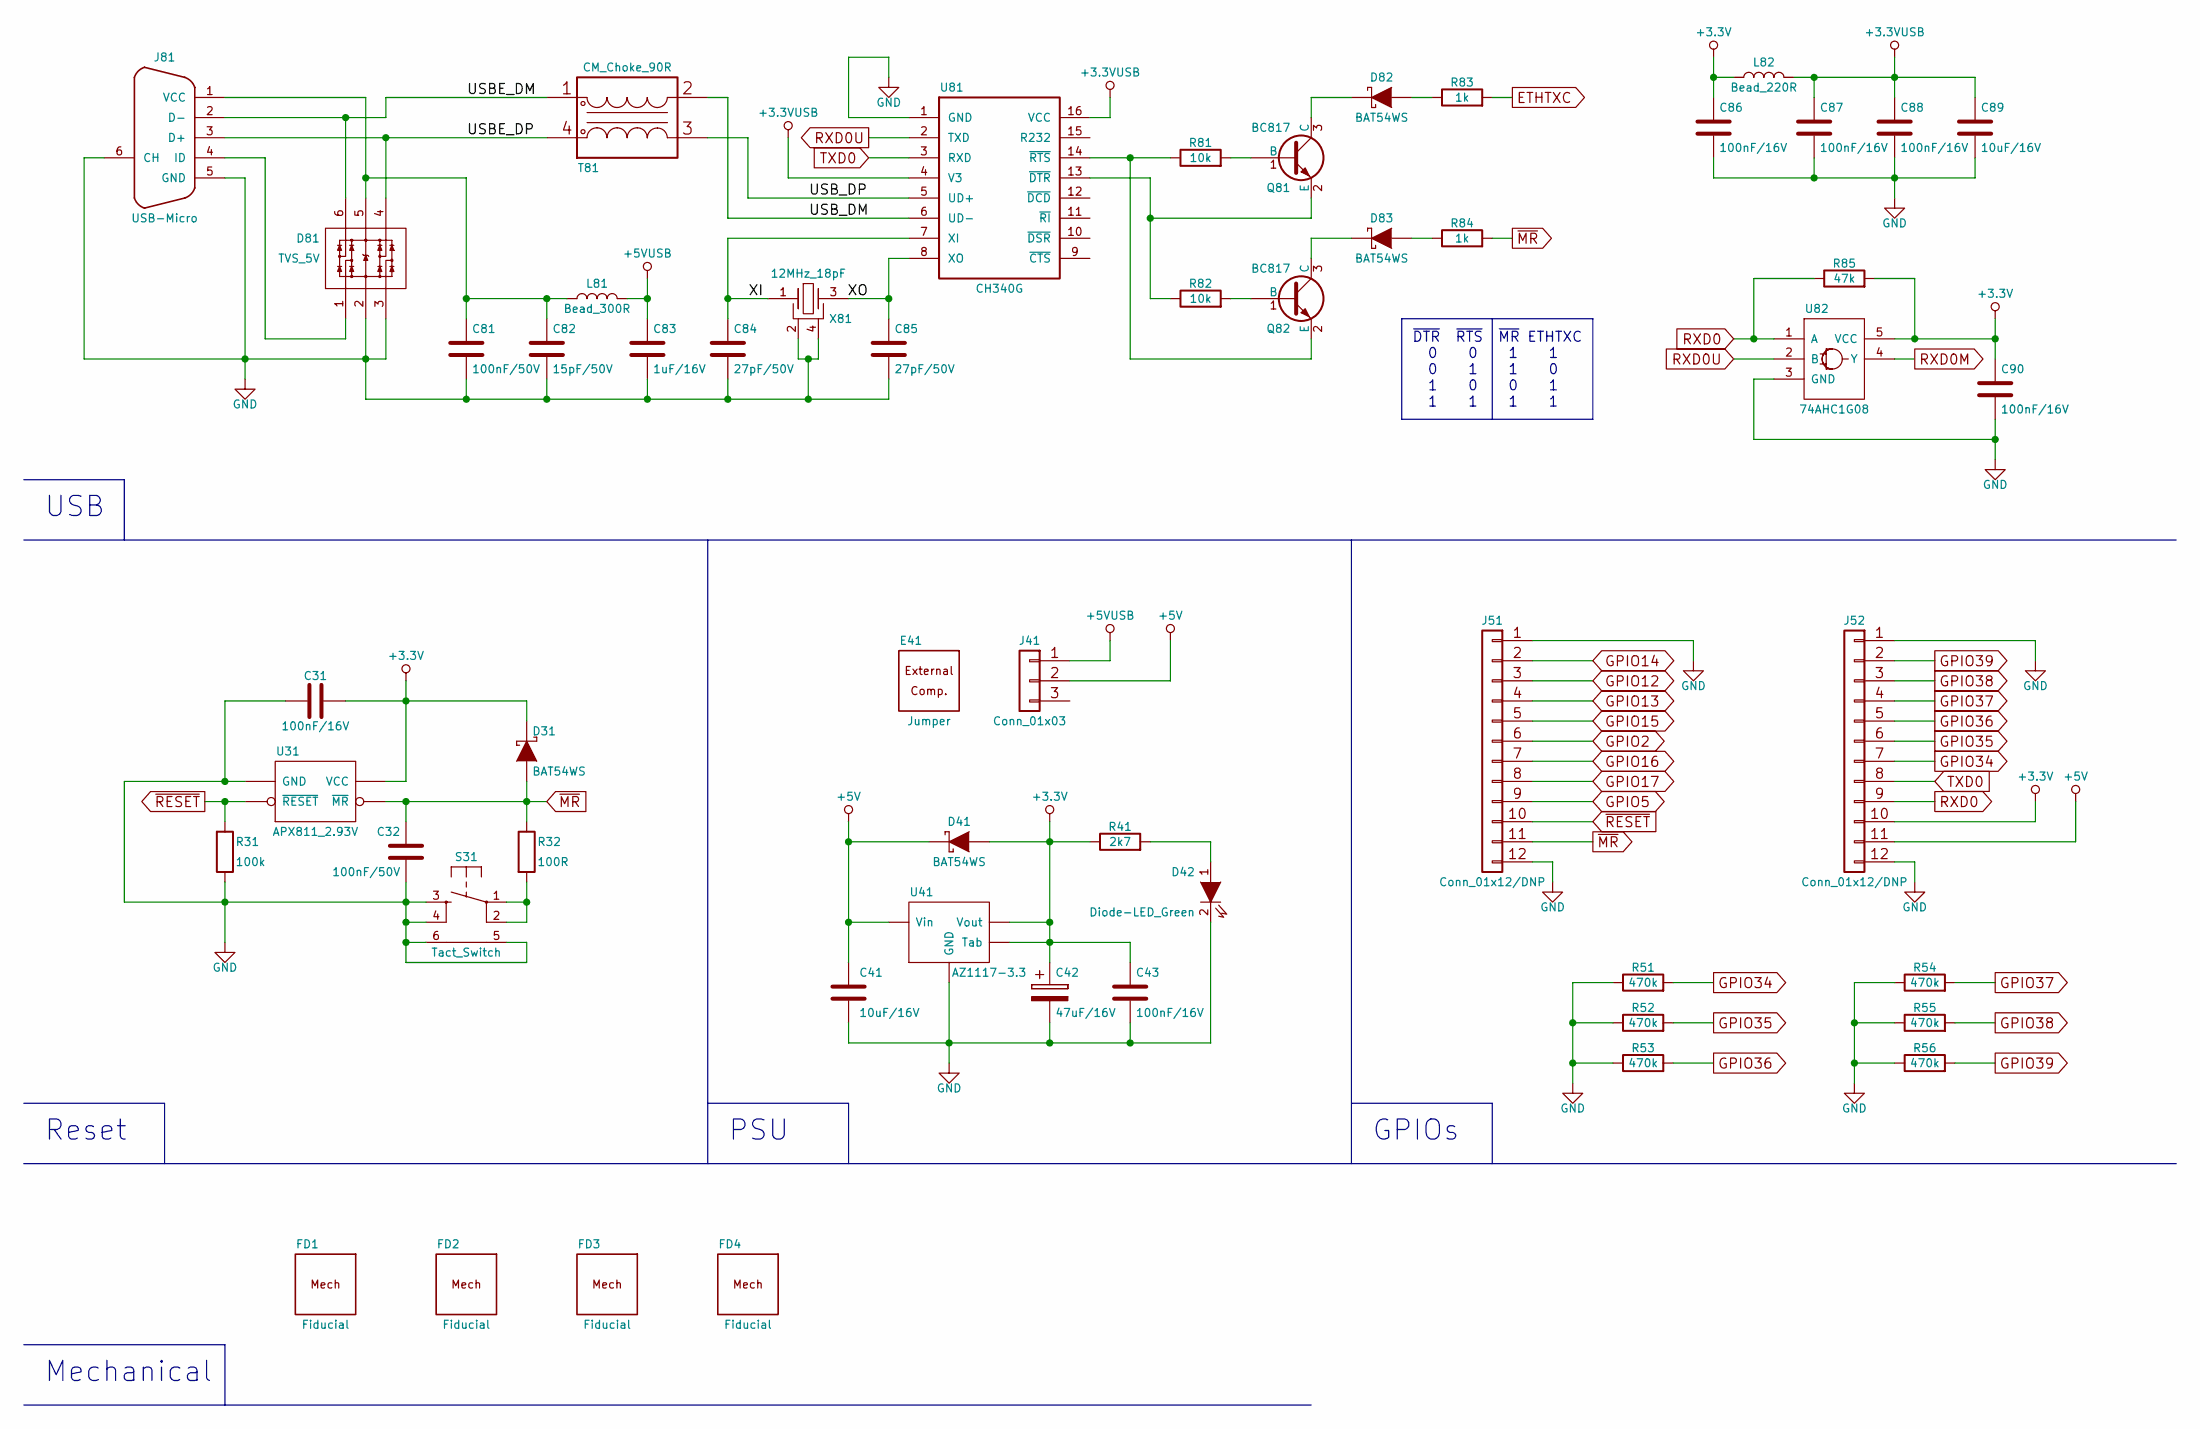
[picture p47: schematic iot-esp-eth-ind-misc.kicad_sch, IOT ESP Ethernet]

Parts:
C31, C43, C86, C87, C88, C90: 100nF/16V; SM0402C; Tolerance 10%; PartNumber CL05B104KO5NNNC; Digikey 1276-1001-1-ND
C32: 100nF/50V; SM0603C; Tolerance 10%; PartNumber CL10B104KB8NNNC; Digikey 1276-1000-1-ND
C41, C89: 10uF/16V; SM0805C; Tolerance 10%; PartNumber CL21B106KOQNNNE; Digikey 1276-2872-1-ND
C42: 47uF/16V; SMD-C-6032; Tolerance 10%; PartNumber TAJC476K016RNJ; Digikey 478-1718-1-ND
C81: 100nF/50V; SM0402C; Tolerance 10%; PartNumber CC0402KRX7R9BB104; Digikey 311-3566-1-ND
C82: 15pF/50V; SM0402C; Tolerance 5%; PartNumber CC0402JRNPO9BN150; Digikey 311-1017-1-ND
C83: 1uF/16V; SM0603C; Tolerance 10%; PartNumber CC0603KRX7R7BB105; Digikey 311-1446-1-ND
C84, C85: 27pF/50V; SM0402C; Tolerance 5%; PartNumber CC0402JRNPO9BN270; Digikey 311-1019-1-ND
D31, D41, D82, D83: BAT54WS; SOD323; Tolerance _; PartNumber BAT54WS_R1_00001; Digikey 3757-BAT54WS_R1_00001CT-ND
D42: Diode-LED_Green; led-SM0603_Green; Tolerance _; PartNumber LTST-C191KGKT; Digikey 160-1446-1-ND
D81: TVS_5V; SOT23-6L; Tolerance _; PartNumber 824015; Digikey 732-4467-1-ND
E41: Jumper; N.A.; Tolerance _; PartNumber X1301-B1NIB; Digikey !S9345-ND
FD1, FD2, FD3, FD4: Fiducial; fiducial_sc_D1_M3mm; Tolerance _; PartNumber _; Digikey _
J41: Conn_01x03; sil-1.27mm-3P; Tolerance _; PartNumber X1311WV-03J-C18D27; Digikey !SAM10238-ND
J51, J52: Conn_01x12/DNP; sil-12P; Tolerance _; PartNumber X6511WV-12H-C60D30; Digikey !S1012EC-12-ND
J81: USB-Micro; usb-629105136821; Tolerance _; PartNumber 629105136821; Digikey 732-3155-1-ND
L81: Bead_300R; SM0603L; Tolerance 25%; PartNumber 742792641; Digikey 732-1592-1-ND
L82: Bead_220R; SM0402L; Tolerance 25%; PartNumber 742792780; Digikey 732-1569-1-ND
Q81, Q82: BC817; SOT23-3; Tolerance _; PartNumber BC817-40-215; Digikey 1727-2919-1-ND
R31: 100k; SM0402; Tolerance 1%; PartNumber RC0402FR-07100KL; Digikey 311-100KLRCT-ND
R32: 100R; SM0402; Tolerance 1%; PartNumber RC0402FR-07100RL; Digikey 311-100LRCT-ND
R41: 2k7; SM0402; Tolerance 1%; PartNumber RC0402FR-072K7L; Digikey 311-2.70KLRCT-ND
R51, R52, R53, R54, R55, R56: 470k; SM0402; Tolerance 1%; PartNumber RC0402FR-07470KL; Digikey 311-470KLRCT-ND
R81, R82: 10k; SM0402; Tolerance 1%; PartNumber RC0402FR-0710KL; Digikey 311-10.0KLRCT-ND
R83, R84: 1k; SM0402; Tolerance 1%; PartNumber RC0402FR-071KL; Digikey 311-1.00KLRCT-ND
R85: 47k; SM0402; Tolerance 1%; PartNumber RC0402FR-0747KL; Digikey 311-47.0KLRCT-ND
S31: Tact_Switch; switch-WE-WS-TASV-3x2.6_H1.4mm; Tolerance _; PartNumber 435171014816; Digikey 732-435171014816CT-ND
T81: CM_Choke_90R; tr-smd-WE-CNSW_0805; Tolerance _; PartNumber 744231091; Digikey 732-3198-1-ND
U31: APX811_2.93V; SOT143-4; Tolerance 2%; PartNumber APX811-29UG-7; Digikey APX811-29UG-7DICT-ND
U41: AZ1117-3.3; SOT223; Tolerance 1%; PartNumber AZ1117IH-3.3TRG1; Digikey AZ1117IH-3.3TRG1DICT-ND
U81: CH340G; SO16_4x10.5_P1.27mm; Tolerance _; PartNumber CH340G; Digikey _
U82: 74AHC1G08; SOT23-5L; Tolerance _; PartNumber SN74AHC1G08DBVR; Digikey 296-1091-1-ND
X81: 12MHz_18pF; xtal-3.2x2.5mm_4pin; Tolerance 20ppm; PartNumber RH100-12.000-18-2020-EXT-TR; Digikey 2151-RH100-12.000-18-2020-EXT-TRCT-ND

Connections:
+3.3V: C31.1, C42.1, C43.1, C86.1, C90.1, D31.2 (K), D41.1 (A), J52.10, L82.1, R41.1, R85.2, U31.4 (VCC), U41.2 (Vout), U41.4 (Tab), U82.5 (VCC); also elsewhere on the board
+3.3VUSB: C87.1, C88.1, C89.1, L82.2, U81.4 (V3), U81.16 (VCC)
+5V: C41.1, D41.2 (K), J41.2, J52.11, U41.3 (Vin); also elsewhere on the board
+5VUSB: C83.1, J41.1, L81.2
/misc/USBE_DM: D81.6 (IO4), J81.2 (D-), T81.1
/misc/USBE_DP: D81.4 (IO3), J81.3 (D+), T81.4
/misc/USB_DM: T81.2, U81.6 (UD-)
/misc/USB_DP: T81.3, U81.5 (UD+)
/misc/XI: C84.1, U81.7 (XI), X81.1 (A)
/misc/XO: C85.1, U81.8 (XO), X81.3 (B)
ETHTXC: R83.2; also elsewhere on the board
GND: C31.2, C32.2, C41.2, C42.2, C43.2, C81.2, C82.2, C83.2, C84.2, C85.2, C86.2, C87.2, C88.2, C89.2, C90.2, D42.2 (K), D81.2 (GND), D81.3 (IO2), J51.1, J51.12, J52.1, J52.12, J81.5 (GND), J81.6 (CH), R31.1, R51.1, R52.1, R53.1, R54.1, R55.1, R56.1, S31.3, S31.4, S31.5, S31.6, U31.1 (GND), U41.1 (GND), U81.1 (GND), U82.3 (GND), X81.2 (GND), X81.4 (GND); also elsewhere on the board
GPIO2: J51.6; also elsewhere on the board
GPIO5: J51.9; also elsewhere on the board
GPIO12: J51.3; also elsewhere on the board
GPIO13: J51.4; also elsewhere on the board
GPIO14: J51.2; also elsewhere on the board
GPIO15: J51.5; also elsewhere on the board
GPIO16: J51.7; also elsewhere on the board
GPIO17: J51.8; also elsewhere on the board
GPIO34: J52.7, R51.2; also elsewhere on the board
GPIO35: J52.6, R52.2; also elsewhere on the board
GPIO36: J52.5, R53.2; also elsewhere on the board
GPIO37: J52.4, R54.2; also elsewhere on the board
GPIO38: J52.3, R55.2; also elsewhere on the board
GPIO39: J52.2, R56.2; also elsewhere on the board
unnamed: C81.1, C82.1, D81.5 (VDD), J81.1 (VCC), L81.1
unnamed: D42.1 (A), R41.2
unnamed: D81.1 (IO1), J81.4 (ID)
unnamed: D82.1 (A), R83.1
unnamed: D82.2 (K), Q81.3 (C)
unnamed: D83.1 (A), R84.1
unnamed: D83.2 (K), Q82.3 (C)
unnamed: Q81.1 (B), R81.2
unnamed: Q81.2 (E), R82.1, U81.13 (~DTR)
unnamed: Q82.1 (B), R82.2
unnamed: Q82.2 (E), R81.1, U81.14 (~RTS)
unnamed: R32.2, S31.1, S31.2
RXD0: J52.9, R85.1, U82.1 (A); also elsewhere on the board
RXD0M: U82.4 (Y); also elsewhere on the board
RXD0U: U81.2 (TXD), U82.2 (B)
TXD0: J52.8, U81.3 (RXD); also elsewhere on the board
~MR: C32.1, D31.1 (A), J51.11, R32.1, R84.2, U31.3 (~MR); also elsewhere on the board
~RESET: J51.10, R31.2, U31.2 (~RESET); also elsewhere on the board

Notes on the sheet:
Reset
USB
Mechanical
PSU
~{DTR} ~{RTS} ~{MR} ETHTXC 0 0 1 1 0 1 1 0 1 0 0 1 1 1 1 1
GPIOs

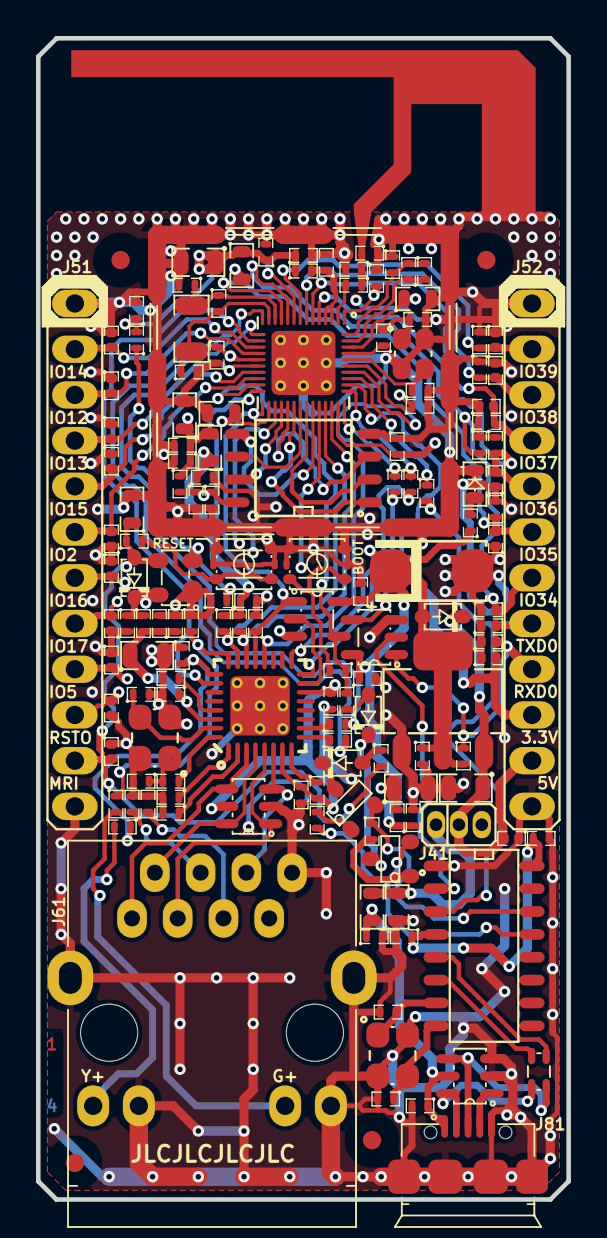
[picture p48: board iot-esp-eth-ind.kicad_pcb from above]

Board: 4 copper layers, 29.5 x 64.5 mm, 150 parts (0 on the bottom side), 97 nets.
